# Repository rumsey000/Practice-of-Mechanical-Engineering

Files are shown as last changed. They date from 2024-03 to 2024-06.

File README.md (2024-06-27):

# 機械工程實務第二十六組專題
## 專題目標
本學年度機械⼯程實務將以分組⽅式完成⼀⾞輛的製作，此⾞輛利⽤環境⾵⼒作為驅動源，製作可將⾵⼒轉換為動⼒(如⾵帆)之機構，藉由控制該機構使⾞輛⾏進並轉向，完成⾃主⾏進任務，故名為AeroRide。
## 程式開發
### IMU
#### BY USING DMP
- 量測三軸加速度及三軸角速度，並使用MPU6050的DMP硬體來將前面提及的六項整合演算出yaw、roll和pitch的角度
- 主要使用 [ic2devlib](https://github.com/jrowberg/i2cdevlib) 這個開源程式庫內的檔案進行自動校正和資料讀取
#### BY USING KALMAN FILTER
- 量測三軸加速度及三軸角速度
- 重力加速度在三軸加速度的分量可算出yaw和roll的傾角，但剛開始測量時可能誤差較大。
- 角速度對時間的積分項亦能得出yaw和roll的傾角，但測量時間愈久誤差愈大。
- 使用卡爾曼濾波器來將前兩項融合出新的yaw和roll的傾角，其優勢在於可將其的缺點互相彌補，因而較為精準。
- 主要使用 [TKJ Electronics](https://github.com/TKJElectronics/KalmanFilter) 這個開源程式庫內的檔案進行資料讀取
- 校正部分則另外參考 [這個網站](https://wired.chillibasket.com/2015/01/calibrating-mpu6050/) 的程式並將讀取資料的函數改寫為上述開源程式庫的I2C通訊，將這個校正程式先跑一次後，再填入上述程式的偏移量中。
### MOTOR
#### DC motor
-期中使用的馬達，透過程式調整PID參數來達成角度控制
#### Servo motor
-期末使用的馬達，直接對MG996R輸PWM訊號來讓控制角度

## 參考網站
### ARDUINO
- [Arduino uno R3](https://docs.arduino.cc/resources/datasheets/A000066-datasheet.pdf)
- [SerialPlot（序列埠繪圖家）工具軟體（二）：安裝與執行SerialPlot - 超圖解系列圖書](https://swf.com.tw/?p=1591)
- [SerialPlot - Realtime Plotting Software | Hackaday.io](https://hackaday.io/project/5334-serialplot-realtime-plotting-software)
- [[C觀念] volatile 的用法和用意 @ 不會的就放這邊 :: 痞客邦 ::](https://anal02.pixnet.net/blog/post/117485340-%5Bc%5D-volatile-%E7%9A%84%E7%94%A8%E6%B3%95%E5%92%8C%E7%94%A8%E6%84%8F)
- [浅析C语言之uint8_t / uint16_t / uint32_t /uint64_t-CSDN博客](https://blog.csdn.net/mary19920410/article/details/71518130)
- [Arduino教程：使用millis()代替delay() – 趣讨教](https://www.qutaojiao.com/21429.html)
- [Arduino自定義庫的編寫 - 台部落](https://www.twblogs.net/a/5b833c9f2b71771e35c1ccf3)
### IMU
- [MPU-6000-Register-Map1.pdf](https://invensense.tdk.com/wp-content/uploads/2015/02/MPU-6000-Register-Map1.pdf)
- [I2C总线和通信协议详解](https://zhuanlan.zhihu.com/p/678229227)
- [Calibrating & Optimising the MPU6050 – chillibasket](https://wired.chillibasket.com/2015/01/calibrating-mpu6050/)
- [关于MPU6050的数据获取、分析与处理_matlab处理mpu6050原始数据-CSDN博客](https://blog.csdn.net/acktomas/article/details/89087174)
- [ASCII Table / character codes – SS64.com](https://ss64.com/ascii.html)
- [Pitch and Roll Estimation](https://www.nxp.com/docs/en/application-note/AN3461.pdf)
- [MPU6050 DMP freezes after random duration · Issue #519 · jrowberg/i2cdevlib · GitHub](https://github.com/jrowberg/i2cdevlib/issues/519)
- [position - 使用加速度计和陀螺仪计算位移 (MPU6050) - IT工具网](https://www.coder.work/article/6199777)
### DC MOTOR
- [NFP-JGA25-370-1260  12V DC datasheetModel ](https://nfpmotor.com/custom-gear-motor-6v12v24v-model-nfp-jga25-370)
- [3V, 6V, 12V DC Micro Metal Gearmotor JGA12-N20 | NFPmotor.com](https://nfpmotor.com/3v-6v-12v-dc-micro-metal-gearmotor-model-nfp-jga12-n20)
- [[RWG] 全新 高扭力 GM25-370 25GA370 直流減速馬達 帶編碼器 測速碼盤 | 蝦皮購物](https://shopee.tw/-RWG-%E5%85%A8%E6%96%B0-%E9%AB%98%E6%89%AD%E5%8A%9B-GM25-370-25GA370-%E7%9B%B4%E6%B5%81%E6%B8%9B%E9%80%9F%E9%A6%AC%E9%81%94-%E5%B8%B6%E7%B7%A8%E7%A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)
- [Stepper Motor with L298N and Arduino Tutorial (4 Examples)](https://www.makerguides.com/l298n-stepper-motor-arduino-tutorial/)
- [Arduino | 旋轉編碼器模組使用](https://hugheschung.blogspot.com/2018/06/arduino-1.html)
### SERVO MOTOR
- [MG90S_Tower-Pro.pdf](https://www.electronicoscaldas.com/datasheet/MG90S_Tower-Pro.pdf)
- [sg90_datasheet.pdf](http://www.ee.ic.ac.uk/pcheung/teaching/DE1_EE/stores/sg90_datasheet.pdf)
- [[Arduino範例] SG90 Servo伺服馬達](https://blog.jmaker.com.tw/arduino-servo-sg90/)
- [伺服馬達，回授控制入門 - 互動的風格 - Medium](https://medium.com/electronics-%E4%BA%92%E5%8B%95%E9%9B%BB%E5%AD%90/%E5%AF%A6%E9%AB%94%E9%81%8B%E7%AE%97week4-4943b619f476)
- [How to interface SG90 servo motor with Arduino](https://www.simplyiotsensors.com/2021/10/how-to-use-sg-90-servo-motor-with-Arduino.html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,of%20the%20motor%20it%20will%20consume%20100-250%20mA.)
### STEP MOTOR
- [[Arduino範例] ULN2003驅動板+28BYJ-48步進馬達](https://blog.jmaker.com.tw/uln2003-28byj-48/)
- [【產品/介紹】ULN2003 驅動板 + 28BYJ-48 步進馬達 - 台灣樹莓派](https://piepie.com.tw/8199/uln2003-stepper-motor-drive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,%E6%91%A9%E6%93%A6%E5%8A%9B%E7%9F%A9%EF%BC%9A600-1200%20gf.cm%20%E5%BC%95%E5%85%A5%E8%BD%89%E7%9F%A9%EF%BC%9A300%20gf.cm)
### SWITCH
- [《Arduino入門》第五篇：按鍵開關的使用](https://blog.jmaker.com.tw/arduino-buttons/)
- [Debounce on a Pushbutton | Arduino Documentation](https://docs.arduino.cc/built-in-examples/digital/Debounce/)
- [上拉電阻 - 維基百科，自由的百科全書](https://zh.wikipedia.org/zh-tw/%E4%B8%8A%E6%8B%89%E7%94%B5%E9%98%BB)
### MERCHANT
- [宇倉電子-全館(已含稅)開發票, 線上商店 | 蝦皮購物](https://shopee.tw/allen_6833?categoryId=100644&entryPoint=cart&itemId=64927673)
- [今華電子網路商城暨實體門市](https://jin-hua.com.tw/index.aspx)
- [廣華電子商城 - 敦華電子材料有限公司_網路郵購-電子材料-電子零件-臺灣 台中市](https://shop.cpu.com.tw/)
- [祥昌電子｜官方購物網 電子零售批發 電子耗材 IC半導體 儀錶 零組件 影音線材 手工具 電源供應器 3C 電子線](https://www.sconline.com.tw/tw/product/index.php?page=1&kind1=&kw=dc%E6%8E%A5%E9%A0%AD)
- [AWG WIRE TABLE](https://ken-gilbert.com/techstuff/AWG_WIRE_TABLE.html)
### SIMULATOR
- [New Arduino Uno Project - Wokwi Simulator](https://wokwi.com/projects/new/arduino-uno)
- [Circuit design Daring Esboo - Tinkercad](https://www.tinkercad.com/things/0wW5GkK5LwL-daring-esboo/editel?tenant=circuits)
- [BLOCK SVG EDIT V20231029](https://www.block.tw/bse/v20231029/)
- [Block Circuit EDIT](https://www.block.tw/bce/)
- [circuito.io](https://www.circuito.io/app?components=512,11021,11028,7654321)
### 3DCAD
- [麵包板](https://grabcad.com/library/mini-breadboard--1)
- [馬達驅動模組](https://grabcad.com/library/l298n-21)
- [18650電池盒](https://grabcad.com/library/4-x-18650-battery-box-1)
- [9V方型電池盒](https://grabcad.com/library/battery-box-9v-boitier-pour-pile-9-v-avec-interrupteur-on-off-1)
- [Arduino板](https://grabcad.com/library/arduino-uno-r3-11)
- [M4螺帽](https://www.mcmaster.com/products/nuts/hex-nuts~/thread-size~m4/)
- [M3螺帽](https://www.mcmaster.com/products/nuts/hex-nuts~/thread-size~m3/)
- [M3螺栓](https://www.mcmaster.com/products/screws/rounded-head-screws~/thread-size~m3/jis-steel-pan-head-screws/)
- [M4螺栓](https://www.mcmaster.com/products/screws/rounded-head-screws~/jis-steel-pan-head-screws/thread-size~m4/thread-size~m4/)
- [銅柱](https://www.mcmaster.com/products/male-female-threaded-hex-standoffs/male-female-threaded-hex-standoffs-6/thread-size~m3/)
### 成果展示
- <http://www.me.ntu.edu.tw/capstone/project.html>

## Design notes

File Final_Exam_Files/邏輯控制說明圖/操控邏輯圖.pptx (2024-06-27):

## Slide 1

升起、展開風帆

1.5s

按按鈕

0.5s

1.8s

旋轉風帆60度
平行風場

拿滿分
然後回宿舍睡覺

開始
煞車

停止
煞車

煞車

1.5s

3.8s

使用IML使
風帆平行第三風場

煞車

2.5s

使用IML使
風帆平行第一風場

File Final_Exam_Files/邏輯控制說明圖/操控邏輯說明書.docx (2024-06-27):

操控邏輯說明書

在圖1中的Start area將透過按鈕啟動arduino loop程式中的下一階段，而在圖1中的深橘色區塊，將透過程式計時0.5s後，車輪先煞車，再透過一顆mg996r伺服馬達旋轉160度升起主風帆，同時透過兩顆sg90伺服馬達旋轉90度展開側風帆，確認展開後，再鬆開煞車，這段期間預計車子將往前直線前進。

隨後，將透過另一顆mg996r伺服馬達做速度控制旋轉60度來讓其能順利得到風的推力，然後再煞車讓車子減速以避免下滑速度太快撞到草地，之後，透過IMU感測車底盤的旋轉量，將其配合mg996r伺服馬達的旋轉角度讓車身的旋轉不影響目前風帆的方向，讓風帆能持續得到推力，此一過程持續3.8秒讓其最後到達淺橘色區塊的60%分線附近。

隨後車子將煞車2.5秒，讓其不撞到圖1右上方的草地，之後風帆同樣受到IMU與伺服馬達的控制讓其與右上方的風機大致呈30度角，讓風帆得到推力將車子吹到終點。

上述過程大部分都以時間作為主要參數調整，可參考下方圖2。

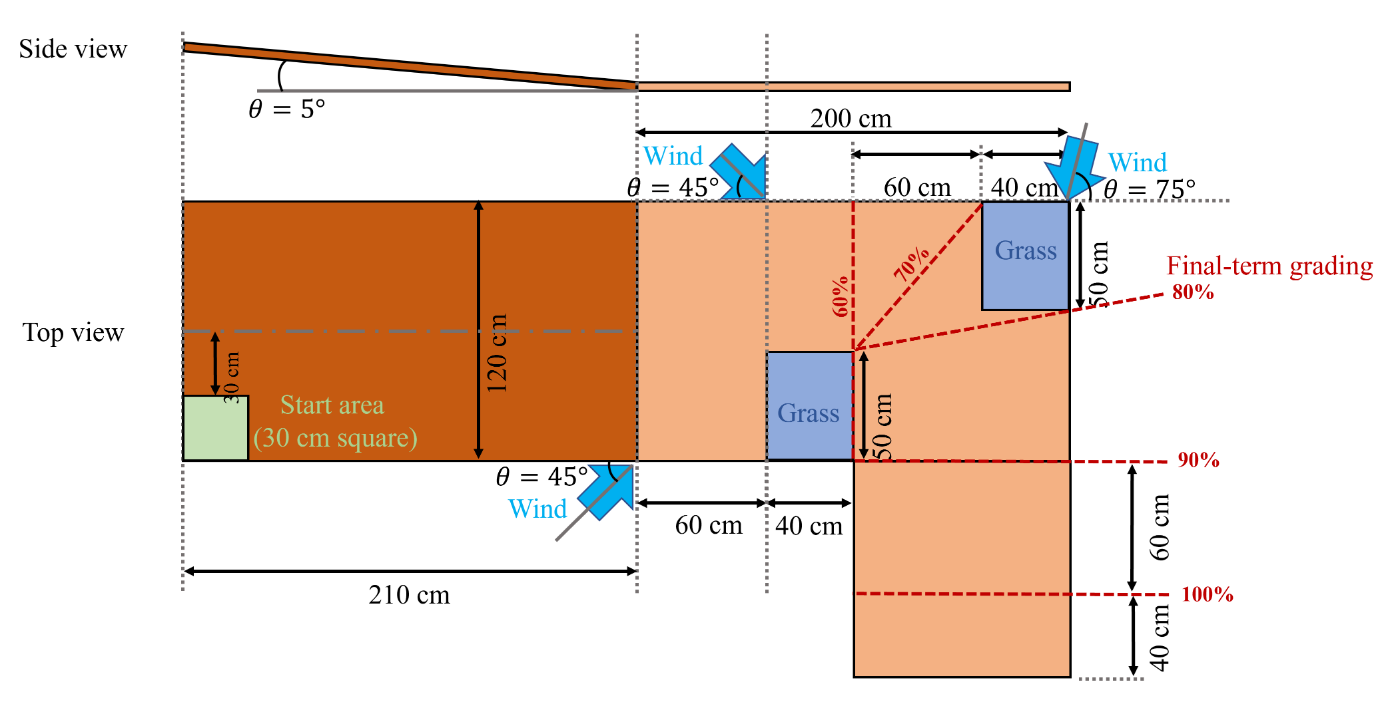
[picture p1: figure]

圖1、賽道示意圖

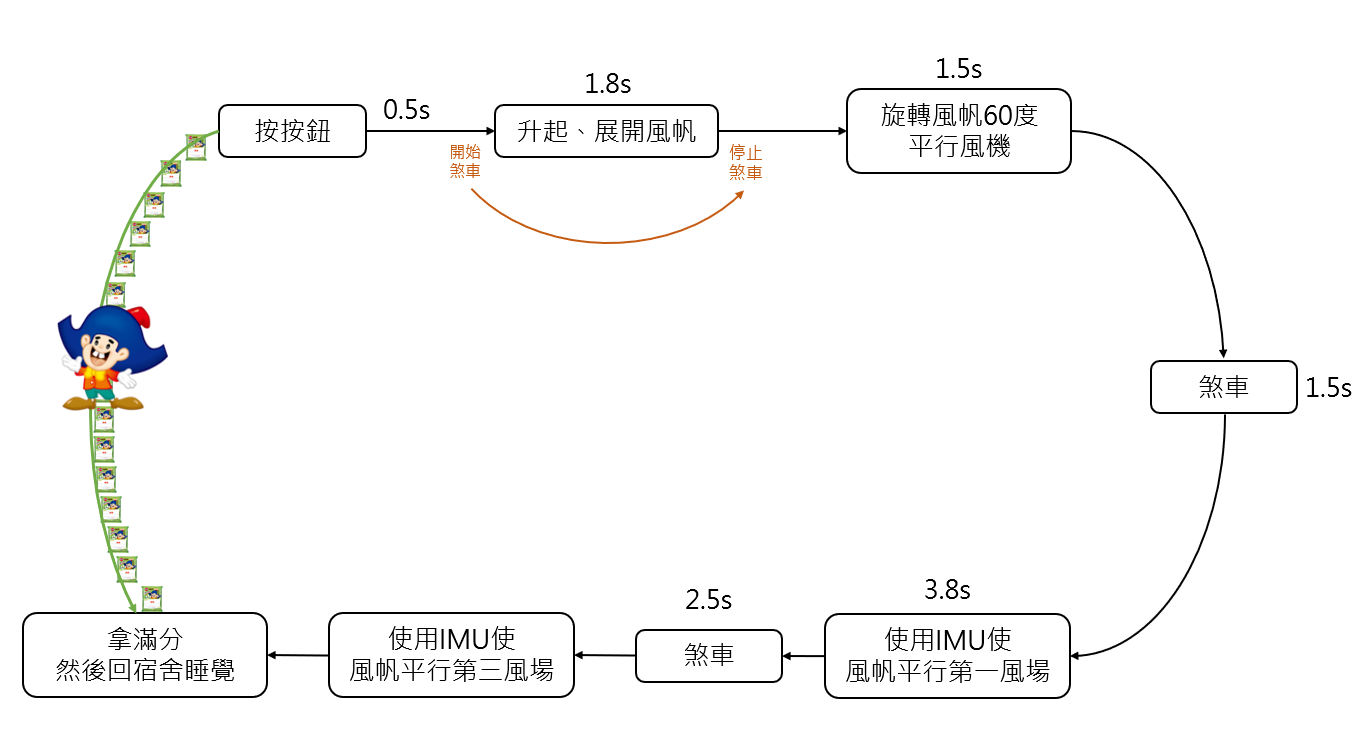
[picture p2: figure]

圖2、時間流程圖

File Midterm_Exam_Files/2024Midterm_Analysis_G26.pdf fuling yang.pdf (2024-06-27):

# Mid-term analysis report

# #OGTh

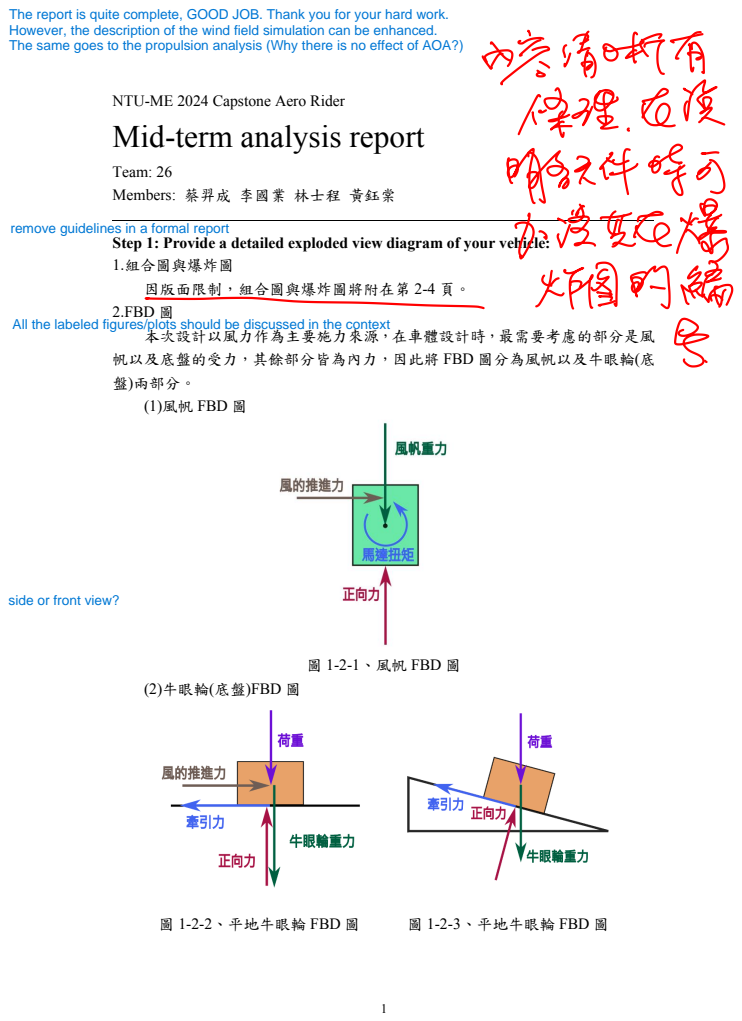
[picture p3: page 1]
圖 1-2-1、風帆 FBD 圖; 圖 1-2-2、平地牛眼輪 FBD 圖; 圖 1-2-3、平地牛眼輪 FBD 圖; Ri G Dre

NTU-ME 2024 Capstone Aero Rider

Team: 26
Members: 蔡羿成 李國業 林士程 黃鈺棠
因版面限制，組合圖與爆炸圖將附在第 2-4 頁。
2.FBD 圖
本次設計以風力作為主要施力來源，在車體設計時，最需要考慮的部分是風
帆以及底盤的受力，其餘部分皆為內力，因此將 FBD 圖分為風帆以及牛眼輪(底
盤)兩部分。
(1)風帆 FBD 圖

Step 1: Provide a detailed exploded view diagram of your vehicle:
1.組合圖與爆炸圖

(2)牛眼輪(底盤)FBD 圖

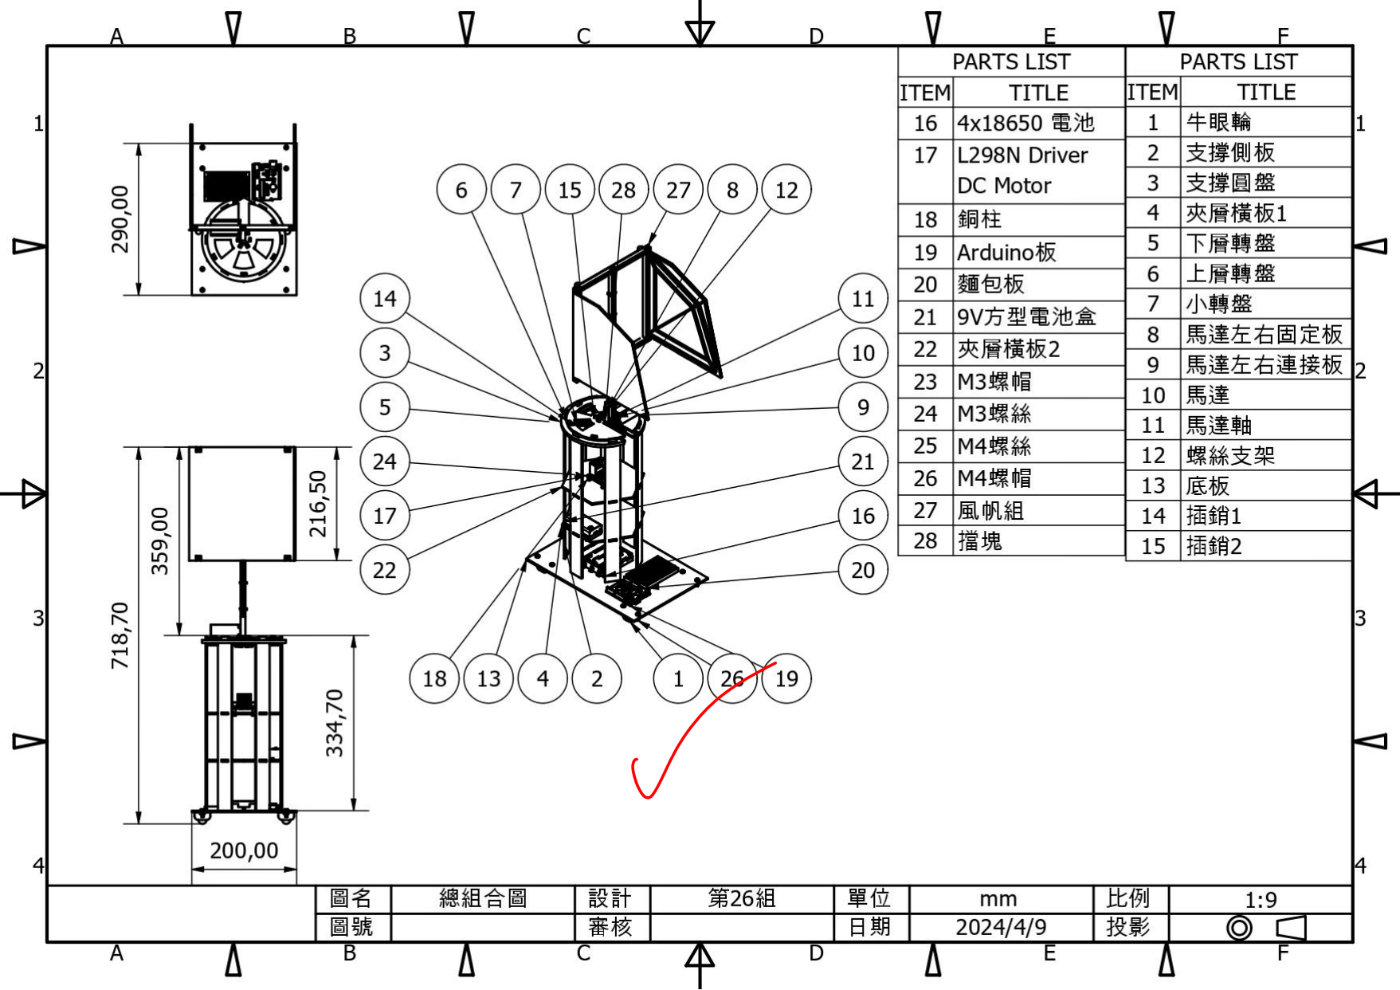
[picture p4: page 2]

2

~

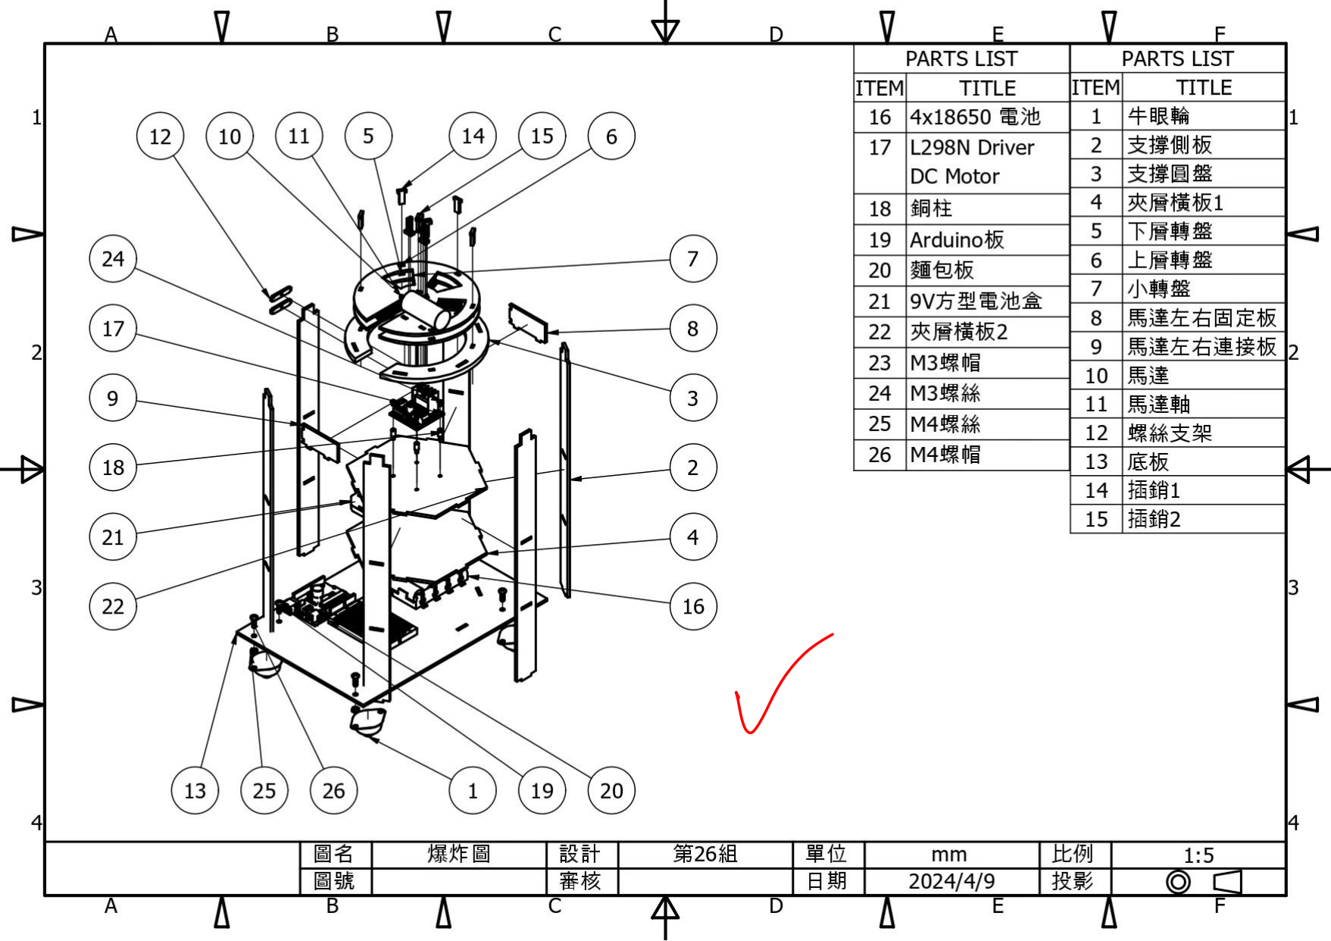
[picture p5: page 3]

3

~

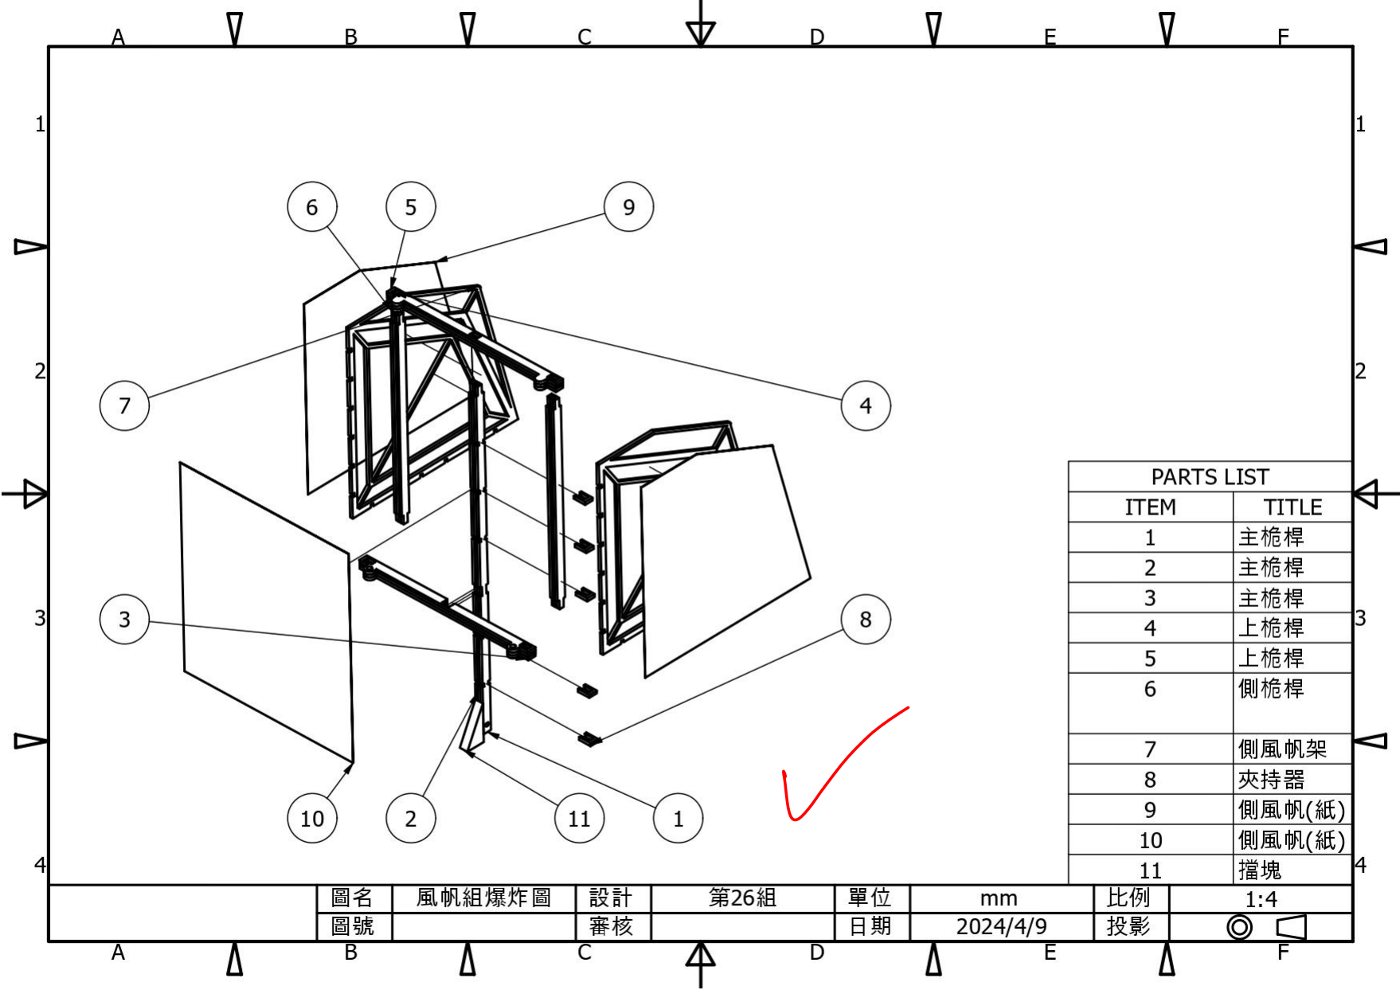
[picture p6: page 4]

4

~

# why not ?

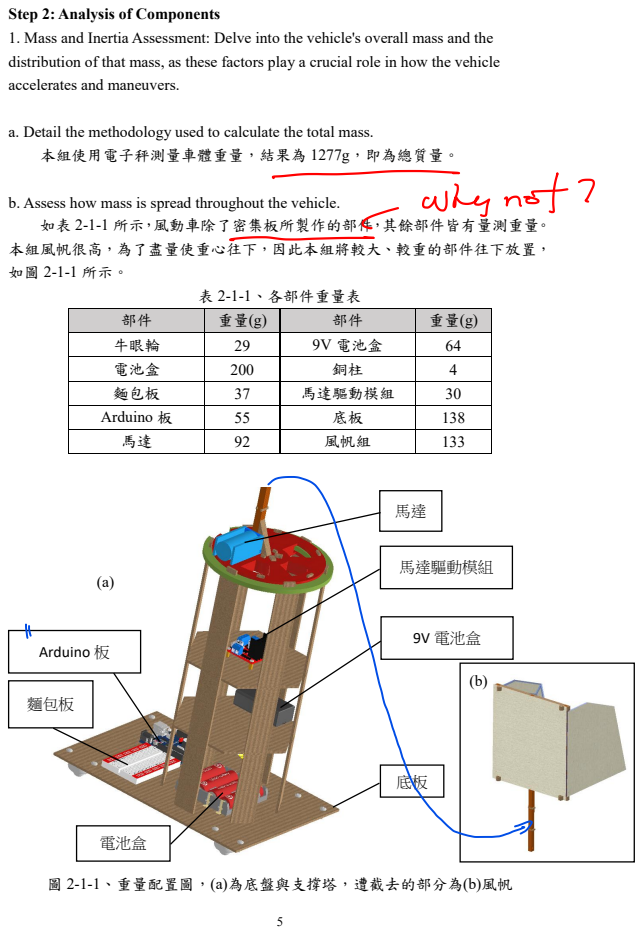
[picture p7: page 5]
表 2-1-1、各部件重量表; 馬達驅動模組; 9V 電池盒; Arduino 板; 麵包板; 電池盒

Step 2: Analysis of Components
1. Mass and Inertia Assessment: Delve into the vehicle's overall mass and the
distribution of that mass, as these factors play a crucial role in how the vehicle
accelerates and maneuvers.

a. Detail the methodology used to calculate the total mass.
本組使用電子秤測量車體重量，結果為 1277g，即為總質量。

b. Assess how mass is spread throughout the vehicle.
如表 2-1-1 所示，風動車除了密集板所製作的部件，其餘部件皆有量測重量。
本組風帆很高，為了盡量使重心往下，因此本組將較大、較重的部件往下放置，

部件 | 重量(g) | 部件 | 重量(g)
牛眼輪 | 29 | 9V 電池盒 | 64
電池盒 | 200 | 銅柱 | 4
麵包板 | 37 | 馬達驅動模組 | 30
Arduino 板 | 55 | 底板 | 138
馬達 | 92 | 風帆組 | 133

圖 2-1-1、重量配置圖，(a)為底盤與支撐塔，遭截去的部分為(b)風帆

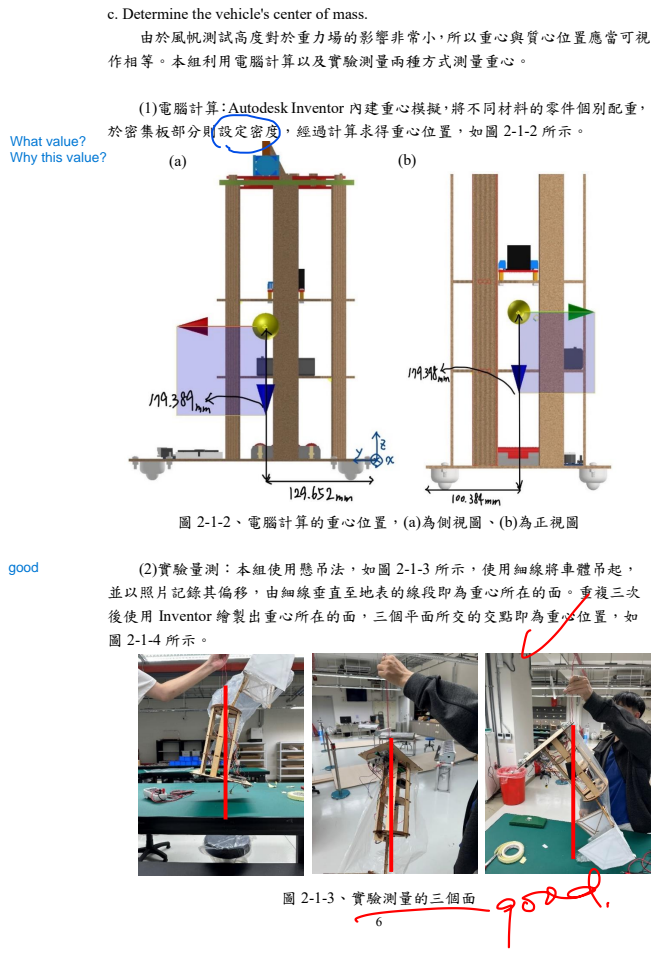
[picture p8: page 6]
圖 2-1-3、實驗測量的三個面; -good.

c. Determine the vehicle's center of mass.
由於風帆測試高度對於重力場的影響非常小，所以重心與質心位置應當可視
作相等。本組利用電腦計算以及實驗測量兩種方式測量重心。

(1)電腦計算：Autodesk Inventor 內建重心模擬，將不同材料的零件個別配重，
於密集板部分則設定密度，經過計算求得重心位置，如圖 2-1-2 所示。

圖 2-1-2、電腦計算的重心位置，(a)為側視圖、(b)為正視圖

(2)實驗量測：本組使用懸吊法，如圖 2-1-3 所示，使用細線將車體吊起，
並以照片記錄其偏移，由細線垂直至地表的線段即為重心所在的面。重複三次
後使用 Inventor 繪製出重心所在的面，三個平面所交的交點即為重心位置，如

圖 2-1-4、Inventor 產生三平面交點與位置

使用兩種方法的重心位置相差為：∆x = 18.51mm， ∆y = 2.79mm，∆z = 5.79mm，透過懸吊法量測重心的位置與 Inventor 模擬的結果在 x 方向差距 1.85cm， 與 inventor 結果相差不大，因此使用 inventor 模擬結果作為重心，在均勻重力場 下，質心位置即為重心位置。

2. Wheel Traction Evaluation: Analyze the grip (friction) between the tires and the surface, a critical factor for steering and braking efficiency. Consider how the vehicle's weight, the type of surface it's on, and the tire material affect traction.
a. Outline the approach for assessing wheel traction.

車子從斜坡上滑下來的過程可視為由重力和車輪牽引力的合力所做的加速 度運動。本組假設牽引力為滾動摩擦力、只與接觸材料和正向力有關，在斜坡上 滑行的過程中則可視為定值，下滑過程便可視為等加速度運動。因此我們選擇量 測車頭由起始點滑下到平面與斜面交界處所需的時間，藉由等加速度公式：

t = √²h

ax

(2 − 2 − 1)

其中 t 為所需時間，h 為車頭自起點滑至平面與斜面交界處的距離，ax是沿斜坡

(a) (b)

# good

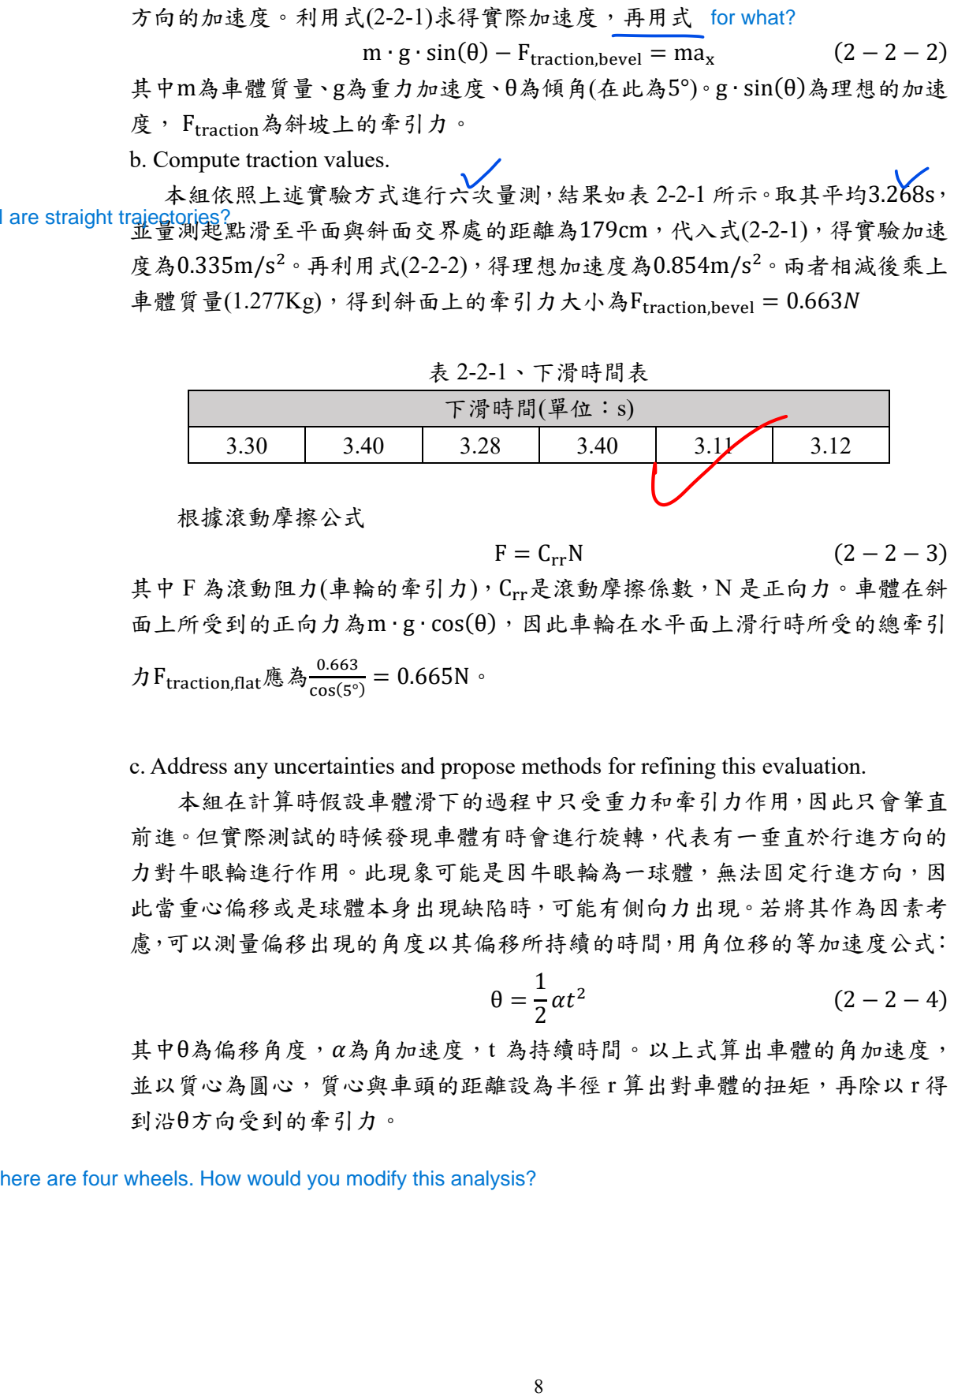
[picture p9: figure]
方向的加速度。利用式(2-2-1)求得實際加速度，再用式; 其中m為車體質量、g為重力加速度、θ為傾角(在此為5°)。g ∙ sin(θ)為理想的加速; 度， Ftraction為斜坡上的牽引力。 b. Compute traction values. 本組依照上述實驗方式進行六次量測，結果如表 2-2-1 所示。取其平均3.268s，; 並量測起點滑至平面與斜面交界處的距離為179cm，代入式(2-2-1)，得實驗加速 度為0.335m/s²; 。再利用式(2-2-2)，得理想加速度為0.854m/s² 。兩者相減後乘上 車體質量(1.277Kg)，得到斜面上的牽引力大小為Ftraction,bevel = 0.663N; 表 2-2-1、下滑時間表; 下滑時間(單位：s); 根據滾動摩擦公式; F = CrrN; 其中 F 為滾動阻力(車輪的牽引力)，Crr是滾動摩擦係數，N 是正向力。車體在斜; 面上所受到的正向力為m ∙ g ∙ cos(θ)，因此車輪在水平面上滑行時所受的總牽引; 力Ftraction,flat應為 0.663 cos(5°) = 0.665N。; 本組在計算時假設車體滑下的過程中只受重力和牽引力作用，因此只會筆直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

m ∙ g ∙ sin(θ) − Ftraction,bevel = max | (2 − 2 − 2)
c. Address any uncertainties and propose methods for refining this evaluation.

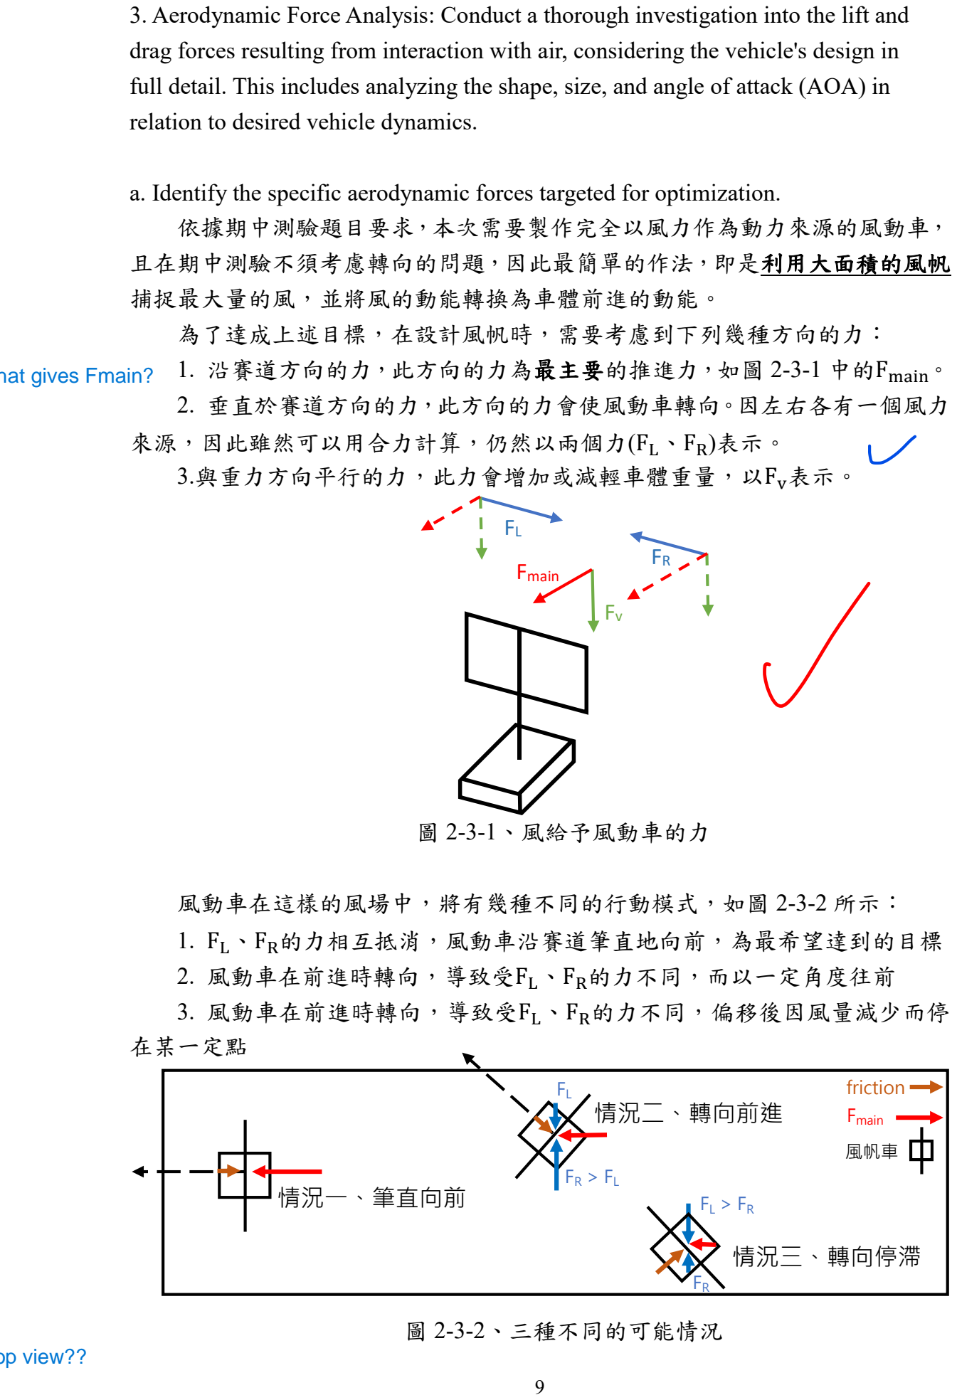
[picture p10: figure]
relation to desired vehicle dynamics.; 依據期中測驗題目要求，本次需要製作完全以風力作為動力來源的風動車，; 且在期中測驗不須考慮轉向的問題，因此最簡單的作法，即是利用大面積的風帆; 捕捉最大量的風，並將風的動能轉換為車體前進的動能。; 為了達成上述目標，在設計風帆時，需要考慮到下列幾種方向的力：; 2. 垂直於賽道方向的力，此方向的力會使風動車轉向。因左右各有一個風力; 來源，因此雖然可以用合力計算，仍然以兩個力(FL、FR)表示。 3.與重力方向平行的力，此力會增加或減輕車體重量，以Fv表示。; 圖 2-3-1、風給予風動車的力; 風動車在這樣的風場中，將有幾種不同的行動模式，如圖 2-3-2 所示：; 1. FL、FR的力相互抵消，風動車沿賽道筆直地向前，為最希望達到的目標; 2. 風動車在前進時轉向，導致受FL、FR的力不同，而以一定角度往前 3. 風動車在前進時轉向，導致受FL、FR的力不同，偏移後因風量減少而停; 在某一定點; 圖 2-3-2、三種不同的可能情況; FR Fmain; 情況一、筆直向前; 情況二、轉向前進; 情況三、轉向停滯; Fmain; friction; 風帆車

3. Aerodynamic Force Analysis: Conduct a thorough investigation into the lift and drag forces resulting from interaction with air, considering the vehicle's design in full detail. This includes analyzing the shape, size, and angle of attack (AOA) in
a. Identify the specific aerodynamic forces targeted for optimization.
1. 沿賽道方向的力，此方向的力為最主要的推進力，如圖 2-3-1 中的Fmain。

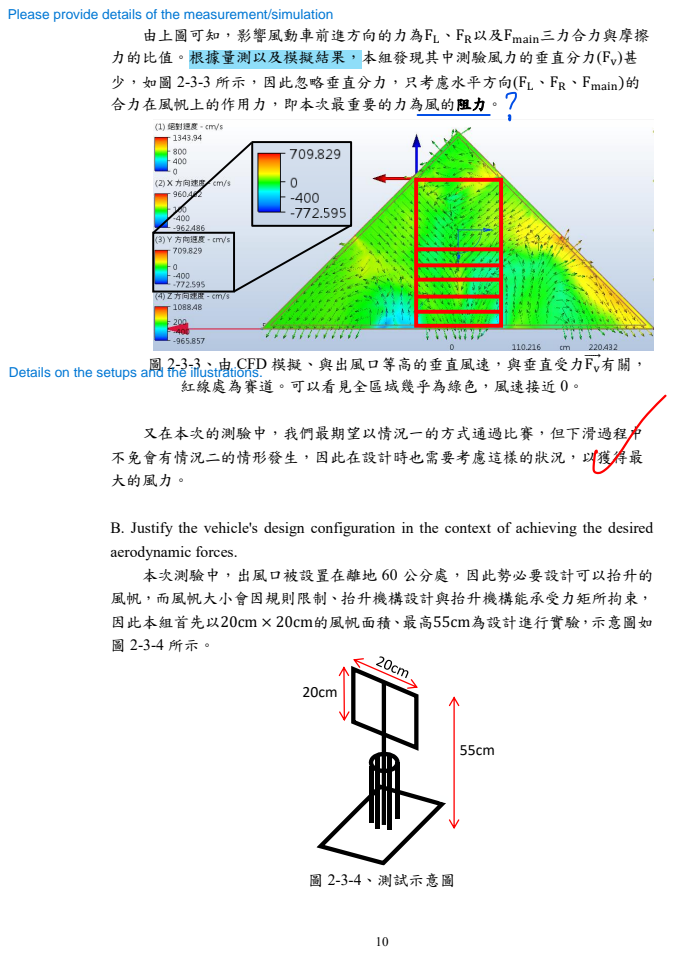
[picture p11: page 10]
圖 2-3-4、測試示意圖

由上圖可知，影響風動車前進方向的力為FL、FR以及Fmain三力合力與摩擦
力的比值。根據量測以及模擬結果，本組發現其中測驗風力的垂直分力(Fv)甚
少，如圖 2-3-3 所示，因此忽略垂直分力，只考慮水平方向(FL、FR、Fmain)的
合力在風帆上的作用力，即本次最重要的力為風的阻力。

圖 2-3-3、由 CFD 模擬、與出風口等高的垂直風速，與垂直受力Fv ⃗ 有關，
紅線處為賽道。可以看見全區域幾乎為綠色，風速接近 0。

又在本次的測驗中，我們最期望以情況一的方式通過比賽，但下滑過程中
不免會有情況二的情形發生，因此在設計時也需要考慮這樣的狀況，以獲得最
大的風力。

B. Justify the vehicle's design configuration in the context of achieving the desired
aerodynamic forces.
本次測驗中，出風口被設置在離地 60 公分處，因此勢必要設計可以抬升的
風帆，而風帆大小會因規則限制、抬升機構設計與抬升機構能承受力矩所拘束，
因此本組首先以20cm × 20cm的風帆面積、最高55cm為設計進行實驗，示意圖如

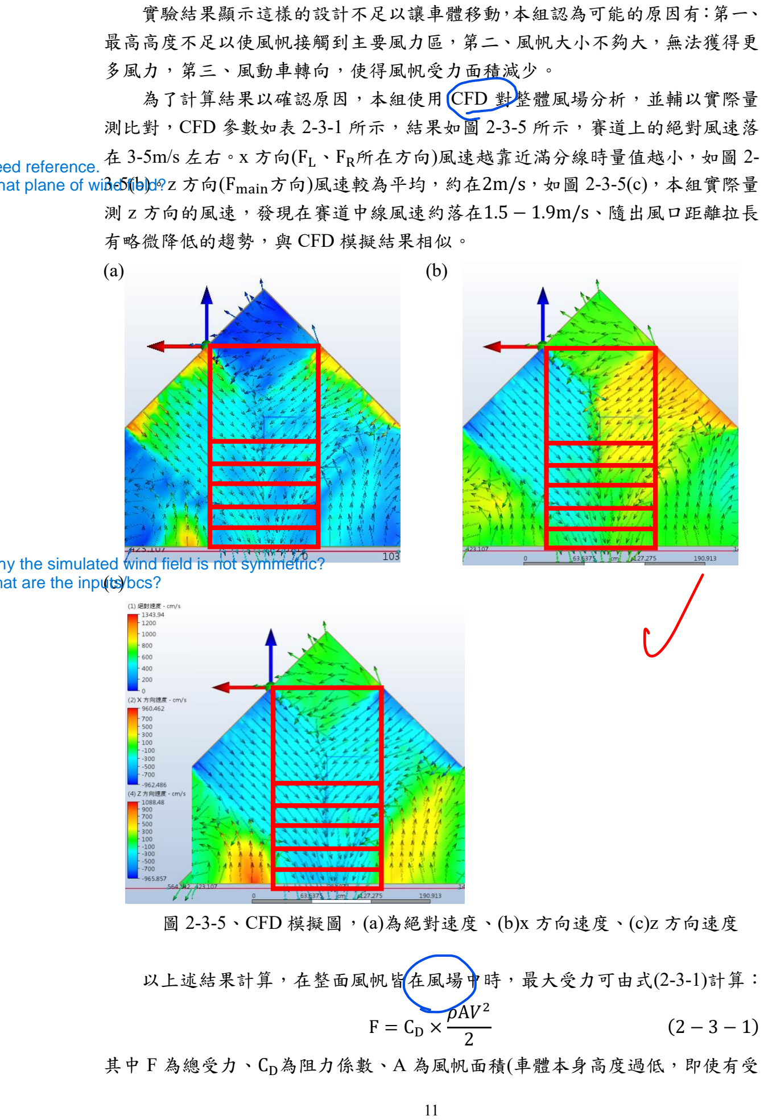
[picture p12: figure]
實驗結果顯示這樣的設計不足以讓車體移動，本組認為可能的原因有：第一、; 最高高度不足以使風帆接觸到主要風力區，第二、風帆大小不夠大，無法獲得更; 多風力，第三、風動車轉向，使得風帆受力面積減少。 為了計算結果以確認原因，本組使用 CFD 對整體風場分析，並輔以實際量; 在 3-5m/s 左右。x 方向(FL、FR所在方向)風速越靠近滿分線時量值越小，如圖 2- 3-5(b)。z 方向(Fmain方向)風速較為平均，約在2m/s，如圖 2-3-5(c)，本組實際量; 測 z 方向的風速，發現在賽道中線風速約落在1.5 − 1.9m/s、隨出風口距離拉長; 有略微降低的趨勢，與 CFD 模擬結果相似。 (a) (b); 圖 2-3-5、CFD 模擬圖，(a)為絕對速度、(b)x 方向速度、(c)z 方向速度; 以上述結果計算，在整面風帆皆在風場中時，最大受力可由式(2-3-1)計算：; F = CD × ρAV²; 其中 F 為總受力、CD為阻力係數、A 為風帆面積(車體本身高度過低，即使有受

測比對，CFD 參數如表 2-3-1 所示，結果如圖 2-3-5 所示，賽道上的絕對風速落

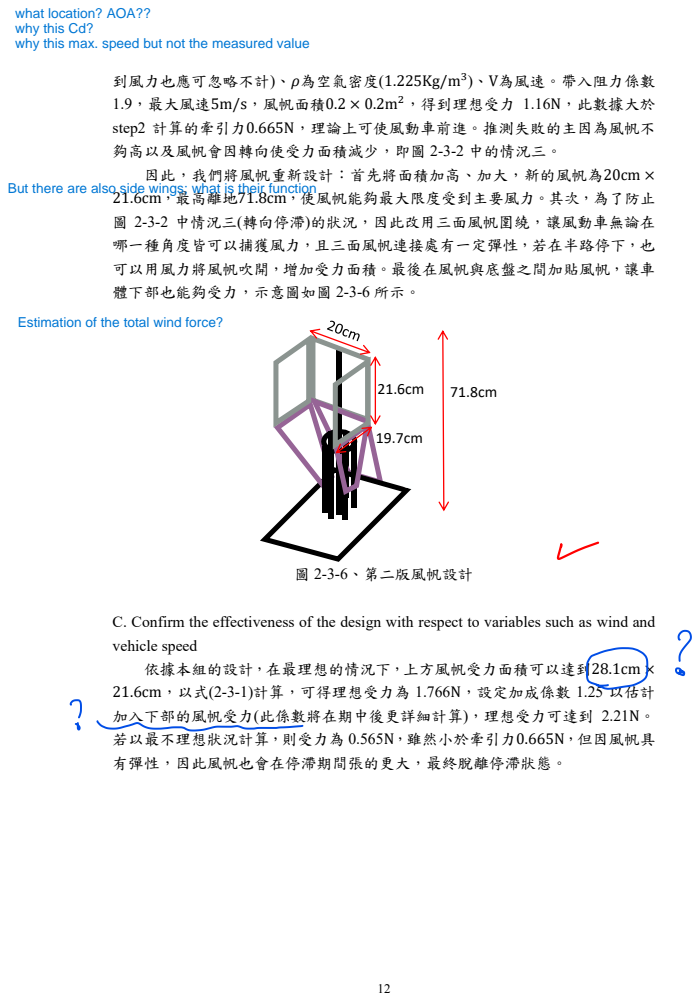
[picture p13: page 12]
圖 2-3-6、第二版風帆設計

到風力也應可忽略不計)、ρ為空氣密度(1.225Kg/m³)、V為風速。帶入阻力係數
1.9，最大風速5m/s，風帆面積0.2 × 0.2m²，得到理想受力 1.16N，此數據大於
step2 計算的牽引力0.665N，理論上可使風動車前進。推測失敗的主因為風帆不
夠高以及風帆會因轉向使受力面積減少，即圖 2-3-2 中的情況三。
因此，我們將風帆重新設計：首先將面積加高、加大，新的風帆為20cm ×
21.6cm，最高離地71.8cm，使風帆能夠最大限度受到主要風力。其次，為了防止
圖 2-3-2 中情況三(轉向停滯)的狀況，因此改用三面風帆圍繞，讓風動車無論在
哪一種角度皆可以捕獲風力，且三面風帆連接處有一定彈性，若在半路停下，也
可以用風力將風帆吹開，增加受力面積。最後在風帆與底盤之間加貼風帆，讓車
體下部也能夠受力，示意圖如圖 2-3-6 所示。

C. Confirm the effectiveness of the design with respect to variables such as wind and
vehicle speed
依據本組的設計，在最理想的情況下，上方風帆受力面積可以達到28.1cm ×
21.6cm，以式(2-3-1)計算，可得理想受力為 1.766N，設定加成係數 1.25 以估計
加入下部的風帆受力(此係數將在期中後更詳細計算)，理想受力可達到 2.21N。
若以最不理想狀況計算，則受力為 0.565N，雖然小於牽引力0.665N，但因風帆具
有彈性，因此風帆也會在停滯期間張的更大，最終脫離停滯狀態。

4. Steering and Unfolding Mechanism Overview: Present a detailed explanation of how your steering or unfolding mechanism can harness wind energy to aid in vehicle navigation.
a. Showcase the mechanism's design and operational principles.
展開機構如圖 2-4-1 所示，由馬達、桅杆及風帆組成，馬達的功能為提供桅杆 轉動所需的動力，風帆的功能則為增加受力面積。

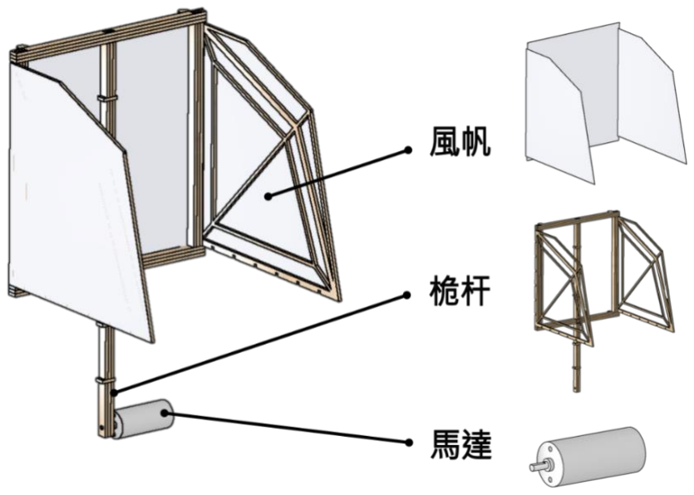
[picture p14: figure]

圖 2-4-1、展開機構
該機構的運作原理是馬達會將桅杆帶動到最高點，再透過風帆盡可能地汲 取風的推力，因為馬達的角度控制是機構能否成功的關鍵，所以本組將該馬達 搭配微控制器、編碼器與馬達驅動模組組成 PID 負回饋控制系統，如圖 2-4-2 所示，來精確地控制馬達軸旋轉到目標角度。
運作時，與馬達軸連接的編碼器將不斷向微控制器發送資料，微控制器再 以該資料推得馬達軸的當下角度，並藉由比較其與目標角度的差和kp、ki與kd 的值來輸出 PWM 與轉向訊號給馬達驅動模組，透過其來供給馬達足夠的電壓 和調整當下的轉速和轉向，最終，讓馬達軸旋轉到目標角度。

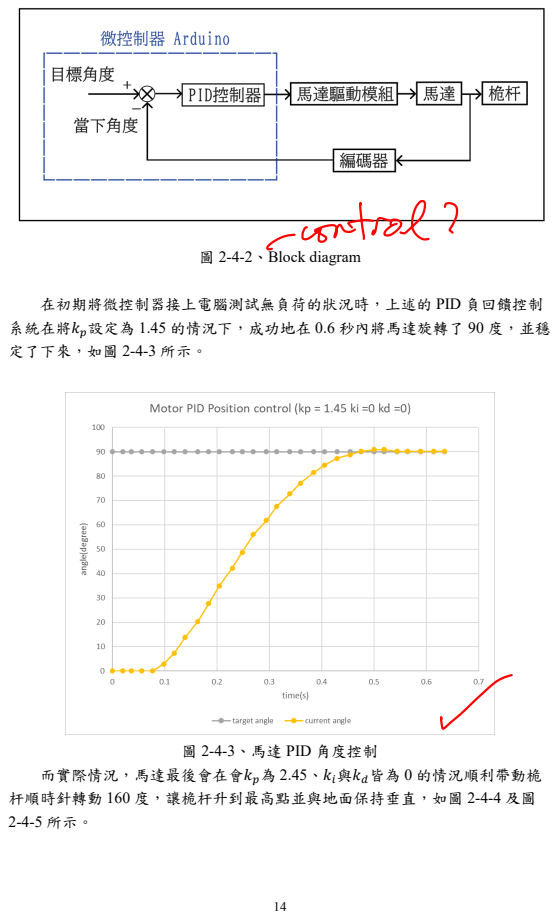
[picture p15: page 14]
圖 2-4-2、Block diagram; -untrol ?

在初期將微控制器接上電腦測試無負荷的狀況時，上述的 PID 負回饋控制
系統在將kp設定為 1.45 的情況下，成功地在 0.6 秒內將馬達旋轉了 90 度，並穩
定了下來，如圖 2-4-3 所示。

圖 2-4-3、馬達 PID 角度控制

而實際情況，馬達最後會在會kp為 2.45、ki與kd皆為 0 的情況順利帶動桅
杆順時針轉動 160 度，讓桅杆升到最高點並與地面保持垂直，如圖 2-4-4 及圖

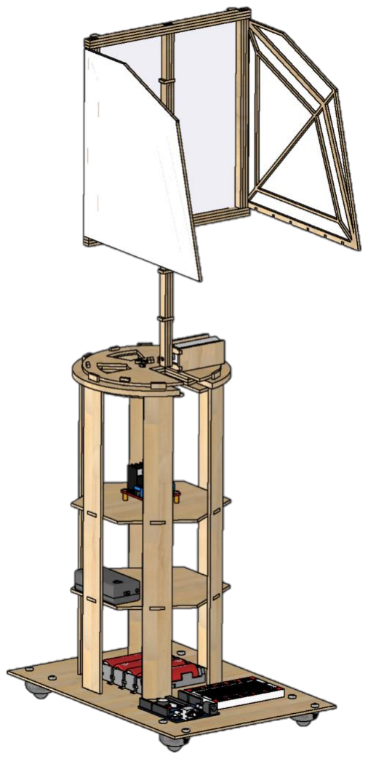
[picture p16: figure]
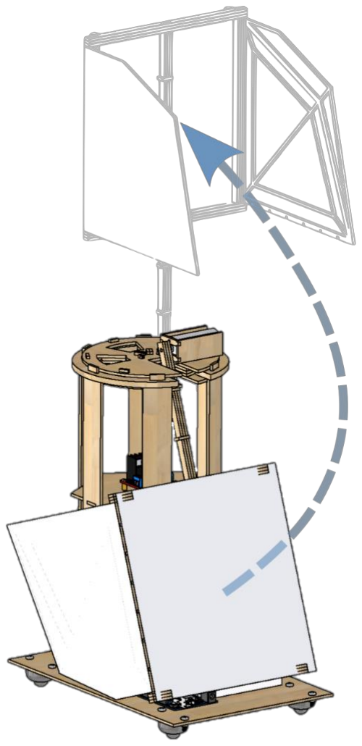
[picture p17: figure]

圖 2-4-4、展開過程示意圖 | 圖 2-4-5、完整展開圖
b. Clarify how the mechanism contributes to vehicle control.
該展開機構會將風帆升到約 50 到 70 公分的高度，因而可阻攔約在 60 公分 處的風，周圍的空氣分子也因此在風帆的受風面產生高壓區，風帆的背風面產生 低壓區，兩區的壓力差與風帆面積積分後算出的推力，將推動風帆帶動車子往風 帆的背風面前進，因而能控制車子的前後方向。
c. Evaluate the mechanism's current performance and suggest potential enhancements or modifications for the future.
該機構的表現能分為風帆效能和馬達控制兩個部分評估。
風帆部分，在馬達有將桅杆上升到最高點的情況下，每次測試階段都能跑 到終點，但所花時間仍然不太穩定，主因是若車子因牛眼輪或風所造成的推力 發生偏轉，就只能靠風帆左右兩側的其中一側得到推力，但由於其面積相對中 間的帆來得小，而造成須花較多時間來前進，因而風帆效能的部分仍有待加 強。
要改善上述的風帆效能，未來可考慮用伺服馬達張開左右兩側的風帆來增 加受力表面積，並使用陀螺儀偵測車子偏轉角度，再根據偏轉程度來調整伺服 馬達的角度，使車體能再被風的推力轉正，以改善偏轉問題，並讓風帆效能有 進一步的提升。
馬達部分，雖然每次放下車子的位置不同都會造成操作環境的稍許變動，

但在調整完 PID 參數後，幾乎測試時都能以肉眼觀察到桅杆有上升到最高點， 因而馬達控制的部分在現階段仍不用太擔心。
但考慮到未來要增加帆及伺服馬達的情況下，kp勢必只能調大，若有觀察 到轉動時有過衝、穩態誤差過大或震盪情況發生時，將根據表 2-4-1 調整ki與kd 來使馬達轉動情形得到改善。此外，由於無另外添購無線通訊的電子元件，目 前仍只能在接電腦的情況下，測得馬達的當前角度與目標角度，因而可在期末 測驗前考慮加裝通訊設備或其他方法來測得馬達在賽道上的實際轉角。

表 2-4-1 PID 參數調整方法表
調整方式 | Rise time | Overshoot | Settling time | Steady state error | Stability
kp增加 | 減少 | 增加 | 小幅增加 | 減少 | 變差
ki增加 | 小幅減少 | 增加 | 增加 | 大幅減少 | 變差
kd增加 | 小幅減少 | 減少 | 減少 | 變動不大 | 便好
Step 3: Vehicle Dynamics Integration
Synthesize the previously discussed elements to formulate a dynamic equation for the Aero Rider.
1. Craft an Equation of Motion (in vector or abstract form):
a. Clearly define each variable, ensuring dimensional consistency across all terms.
b. Provide a detailed explanation for each component of the equation. 運動方程式可以分為斜坡上的方程式以及平地上的方程式： (1)斜坡上的方程式：
m ∙ ⃗g ∙ sin(θ) − F⃗
traction,bevel = ma⃗ x,bevel | (3 − 1 − 1)
F⃗
traction,bevel = CrrN = Crr ∙ m ∙ g ∙ cos(θ) | (3 − 1 − 2)
其中
(a) m為車體質量，單位為Kg
(b) ⃗g 為重力加速度，單位為m/s²
(c) θ為傾角，(2)-(3)組合即為理想的加速度g ∙ sin(θ)
(d) F⃗
traction,bevel為斜坡上的牽引力，單位為 N
(e) a⃗ x,bevel為沿斜坡方向加速度，單位為m/s²
(f) Crr為滾動摩擦係數
值得注意的是式(3-1-1)即為式(2-2-2)，式(3-1-2)即為式(2-2-3)。
(2) 平面上的方程式：
F⃗

wind + F⃗
traction,flat = ma⃗ x,flat | (3 − 1 − 3)
F⃗
traction,flat = mg | (3 − 1 − 4)

其中
(a) F⃗
wind為風給與風動車的力，單位為 N
(b) F⃗
traction,flat為平面上的牽引力，單位為 N
(c) a⃗ x,flat為往終點方向加速度，單位為m/s²
c. Outline the underlying assumptions made in the formulation. 在這些方程式中，我們假設:
(1)車體本身只受重力、牽引力和風力影響
(2)風帆所承受到的風力一直為最大值且不會變化
(3)車體筆直前行，不會旋轉
(4)風帆在受風區時維持垂直於水平面
2. Assess the Validity of Your Equations (through experimental measurements, numerical analyses, etc.):
a. Outline the methodology for using the equation to predict the Aero Rider's dynamics. 上述四條公式皆是以牛頓第二定律為基礎。在式(3-1-1)中，m ∙ g ∙ sin(θ)為沿 斜坡方向下的加速度，減去斜坡上的牽引力Ftraction,bevel，即為實際作用力max。 在(3-1-2)中，詳細說明了Ftraction,bevel即是以滾動摩擦的方式計算，只需要注意正 向力為m ∙ g ∙ cos(θ)。在(3-1-3)中，Fwind為風給與風動車的力，減去平面上的牽 引力Ftraction,flat，即是作用力max。(3-1-4)與(3-1-2)雷同，只需要注意正向力為mg。 以上述四式計算可得風動車在斜面以及在平面上的加速度，並可做進一步處 理獲得速度、時間等資訊。
b. Describe the process for deriving predictions from the equation.
將 step2 中所計算或量測的數據代入式(3-1-1)、式(3-1-2)，即可得知加速度： 1.277 ∙ 9.81 ∙ sin(5°) − F⃗
traction,bevel = 1.277a⃗ x | (3 − 2 − 1)
F⃗
traction,bevel = 0.663 | (3 − 2 − 2)
加速度a⃗ x,bevel為0.335m/s²，再帶入式(2-2-1)：

t = √²h

ax

= √² ∙ 1.79
0.335 | (2 − 2 − 1)

得到滑行時間tbevel = 3.278s，再使用公式：
v = axt ∙ cos(θ) = 0.335 ∙ 3.278 ∙ cos(5) | (3 − 2 − 3)
得終端速度為vbevel = 1.094m/s。將風給予的力設為最理想與最不理想的平均 (F⃗
wind = 1.387N )利用相同方式計算，得到從速度為零自平板上起跑到終點的加 速度a⃗ x,flat為0.565m/s²，滑行時間tflat = 2.661s，終端速度為vflat = 1.503m/s。

c. Benchmark these predictions against real-world behaviors or outcomes.
實驗結果如表 3-2-1 所示，在實驗時，本組發現滑行至平面時，風動車仍會 停頓，持續約 4 秒。由於未記錄在滑坡上的時長，因此只比較從暫停處到終點用 時。 相比於計算數據 2.661 秒，實驗數據大約為兩倍長，推測為風帆的效能估計 太過樂觀所致。
表 3-2-1、各項實驗資料
實驗 | 總時長(s) | 暫停時長(s) 暫停時與終點的距離(m) 暫停處到終點用時(s)
1 | 9.24 | 3.99 | 1.32 | 5.25
2 | 9.14 | 3.82 | 1.35 | 5.32
3 | 9.06 | 4.03 | 1.2 | 5.03
4 | 9.27 | 4.23 | 1.23 | 5.04
5 | 9 | 4.1 | 1.17 | 4.9
6 | 8.77 | 4.03 | 1.06 | 4.74
平均 | 9.08 | 4.0 | 1.22 | 5.05
3. Suggest Improvements for the Modeling/Testing Approach:
a. Reflect on any discrepancies observed between the predictions and actual outcomes. 在實際試驗中，我們發現進入流場的車子並不會隨著風力的推動筆直往前走， 而是會停在原地不動一段時間，然後才被風力推動，而前進所耗費的時間也比計 算來的慢很多。此外，在由斜坡道平面的過程中，也時常出現轉向的情況發生， 這也是在建立運動方程式時未討論到的部分。
b. Speculate on potential sources of error or misalignment in the model or testing process.
我們認為這樣的現象可能來自於對風帆受力的預期過於樂觀，由於風帆會隨 著車體轉向而改變角度，在以不同角度面對風機時車體會有不同的速度，原本的 理想風推力 2.21N 是由理想受力 1.766N 乘上係數 1.25 所得，根據實際情況計算， 加速度的平均值為0.096m/s²，得出的實際推力應為 0.785N，代表我們的風帆並 未能擷取到大部分的風力。此外，我們沒有將平面分成未進入風場以及進入風場 兩部分討論，使得在剛進入平面而尚未進入風場的區段也被計算成有進入風場的 情況，使得用時被低估。
c. Propose strategies to address and rectify these discrepancies for more accurate future modeling.
鑒於上述討論，本組認為需要對以下幾點改善、建立更準確的評估模式：
(1) 除了中線上的風場量測外，本組往後將量測更多個數據點，以求精準
(2) 運動方程式應當加入轉角對車體運動、風帆受力的影響
(3) 平面區段應更細分為未進入風場以即進入風場兩區
(4) 風帆的加成係數需要準確量測或利用(1)中獲得更精確的數據計算

Step 4: Summary and Conclusions
本組利用塔加上抬升風帆的方式將風帆抬至風速最大的區間之中，利用風力 驅動車體移動。風帆以 U 字形設計，確保無論車體如何轉向，風帆皆能夠接收風 力。在沒有 U 字形設計時，車體無法前進；加入 U 字形設計後。在六次的實驗 中，平均耗時 9.08 秒完成一趟測試；在一次的模擬正式測驗中，花費 2 分 06 秒 完成測試且每次均達 100 分線，證實這項設計的成效以及其必要性。 本組的設計優點在於做動機構簡單、方便維修，且設計轉盤，為以後的轉向 保留擴充空間，零件雖較多但體積小，重製、替換成本較低等。缺點在於：在最 極端的情況下仍有可能使車體無法前進，許多需要旋轉的部件會因磨損而需要替 換等。解決方案為將易磨損零件的材質由合板改為 3D 列印之塑膠，增加強度， 風帆設計更好的展開模式，加大受力面積。
對於期末的測試，本組在風帆與機構部分事先保留轉向設計－實際上此時便 可以轉向，但本組有使用插銷固定轉盤－因此在轉向上只需加入機電元件便可， 如圖 4-1 所示。風帆也預留展開設計，可以進一步將最大受力面積擴張為現在的 三倍，如圖 4-2 所示。位置資訊則預計由陀螺儀獲得。

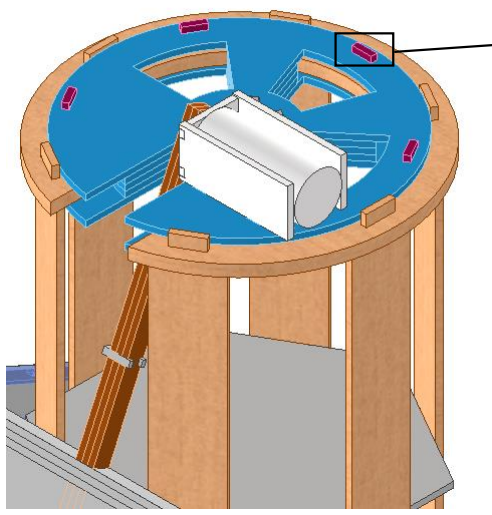
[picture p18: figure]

圖 4-1、轉盤設計，藍色為轉盤，深紅色為插銷

插銷

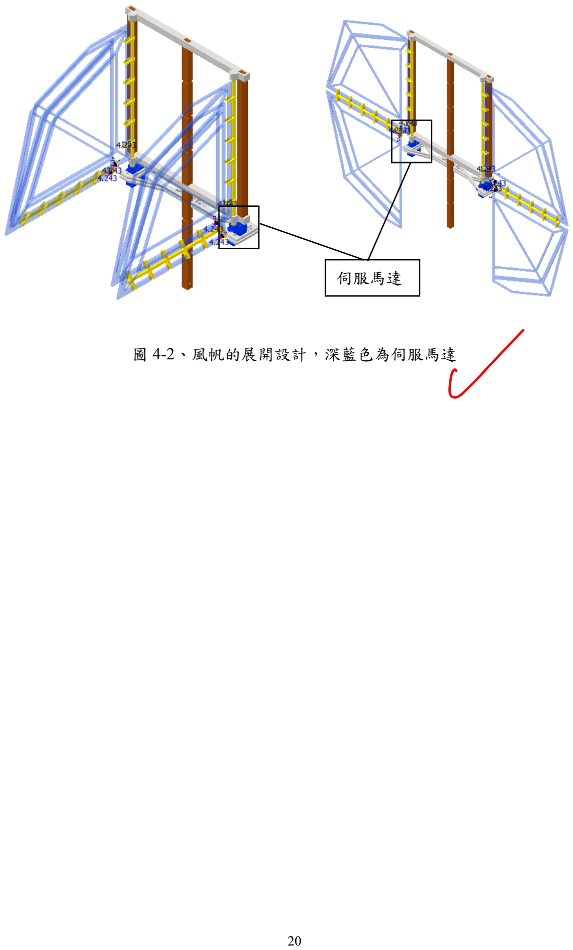
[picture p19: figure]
圖 4-2、風帆的展開設計，深藍色為伺服馬達; 伺服馬達

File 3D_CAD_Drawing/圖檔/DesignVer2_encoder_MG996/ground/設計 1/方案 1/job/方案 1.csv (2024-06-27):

CPU time | 58.133
memory | 163962880
fluid nodes | 67949
solid nodes | 0
fluid elements | 259369
solid elements | 0

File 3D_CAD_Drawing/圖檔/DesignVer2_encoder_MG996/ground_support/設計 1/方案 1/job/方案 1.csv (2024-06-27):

CPU time | 55.381
memory | 164405248
fluid nodes | 67949
solid nodes | 0
fluid elements | 259369
solid elements | 0

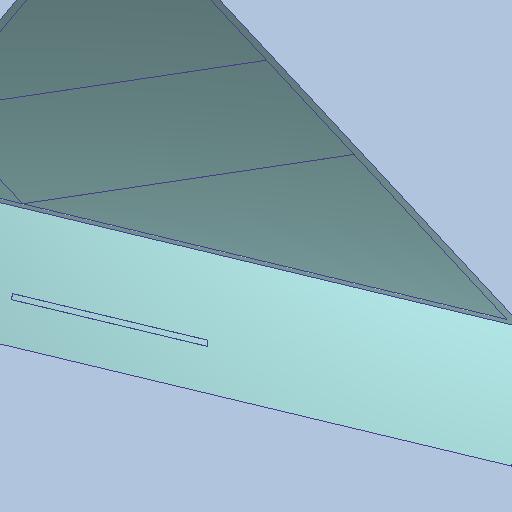
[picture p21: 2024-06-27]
3D_CAD_Drawing/圖檔/DesignVer2_encoder_MG996/ground_support/設計 1/方案 1/thumbnail.jpg

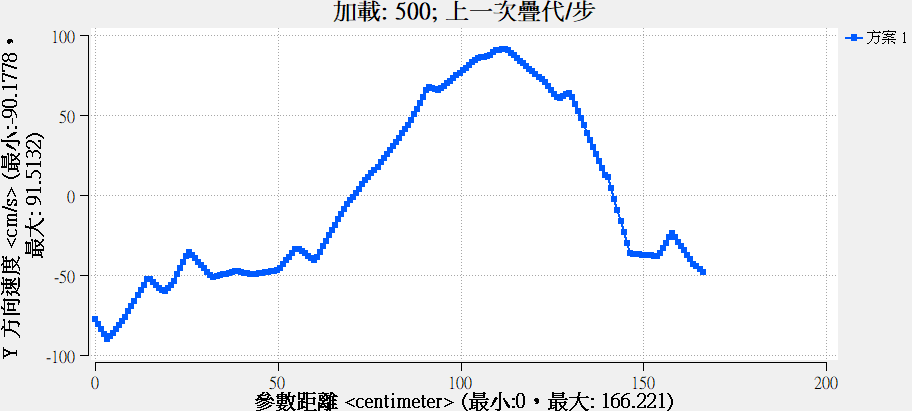
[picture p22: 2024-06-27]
3D_CAD_Drawing/圖檔/DesignVer2_encoder_MG996/ground_support/Y.bmp

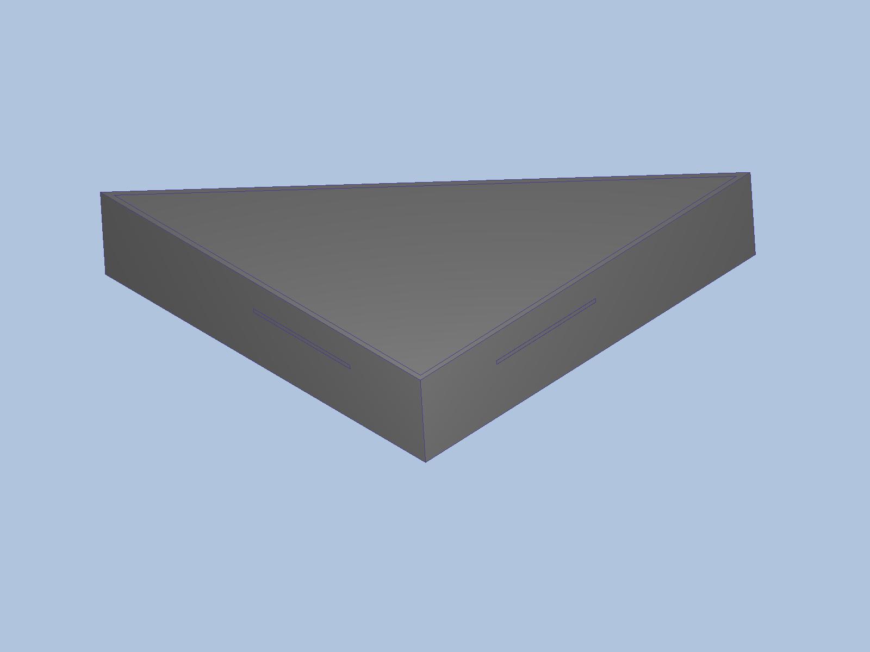
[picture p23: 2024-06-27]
3D_CAD_Drawing/圖檔/DesignVer2_encoder_MG996/ground/preview.jpg

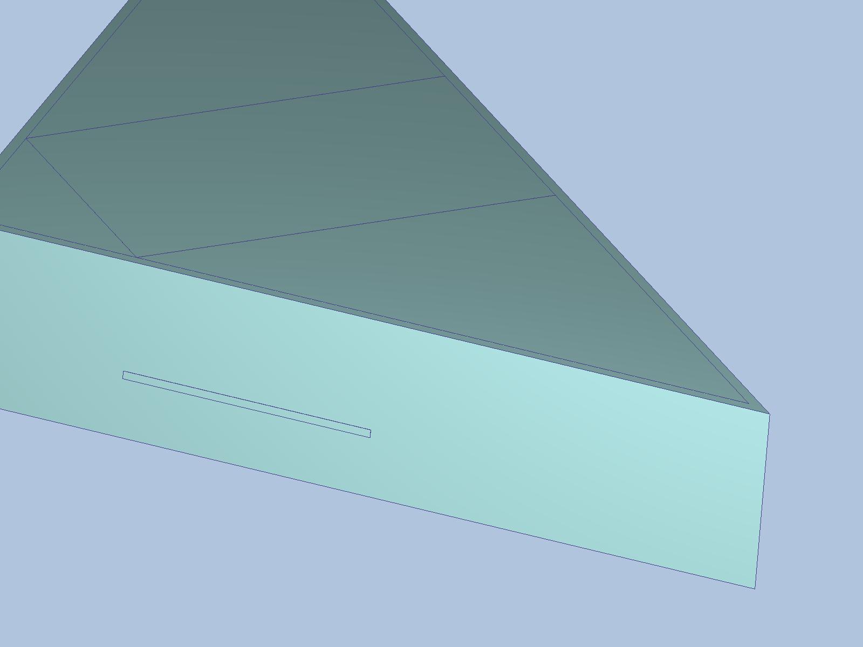
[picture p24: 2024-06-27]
3D_CAD_Drawing/圖檔/DesignVer2_encoder_MG996/ground_support/preview.jpg

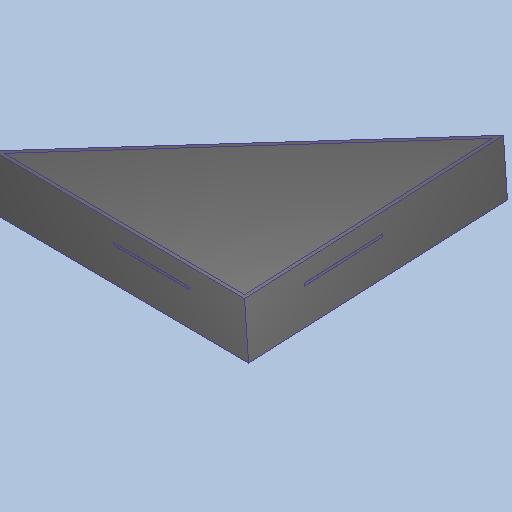
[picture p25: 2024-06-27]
3D_CAD_Drawing/圖檔/DesignVer2_encoder_MG996/ground/設計 1/方案 1/thumbnail.jpg

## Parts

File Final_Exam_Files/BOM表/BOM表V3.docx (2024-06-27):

Bill of Materials

組別 | 26

項次編號 | 零件名稱 | 來源 | 數量 | 單價 | 金額
1 | 9V電池盒 | 祥昌電子 | 1 | 12 | 12
2 | 免焊接 DC插頭 | | 1 | 8 | 8
3 | 18650 電池盒 | | 1 | 70 | 70
4 | 18650鋰電池 | | 4 | 90.25 | 361
5 | Arduino Uno R3 | 蝦皮拍賣https://shopee.tw/jmaker | 1 | 285 | 285
6 | 開關 | | 1 | 4 | 4
7 | 麵包板 | | 2 | 40 | 80
8 | MPU6050 IMU | | 1 | 90 | 90
9 | 光遮斷器模組 | 今華電子 | 2 | 40 | 80
10 | 杜邦線 | | 33 | 1.375 | 45
11 | MG996r 伺服馬達 | | 2 | 180 | 360
12 | SG90伺服馬達 | | 4 | 70 | 280
13 | LM-2596降壓模組 | | 1 | 140 | 140
14 | 9V電池 | 金興發生活百貨 | 1 | 119 | 119
15 | 轉盤滑軌鋼珠 | 蝦皮拍賣https://shopee.tw/angusbao0403 | 10 | 0.1 | 1
16 | M2螺帽 | 實作中心 | 3 | 1 | 3
17 | M3螺絲 | | 3 | 1 | 3
18 | M3螺帽 | | 2 | 2 | 4
19 | M3螺絲 | | 2 | 1 | 2
20 | M4螺帽 | | 8 | 2 | 16
21 | M4螺絲 | | 8 | 1 | 8
22 | 支撐側板 | 課程提供 | 6 | 2 | 12
23 | 支撐圓盤 | | 2 | 2 | 2
24 | 夾層橫板 | | 3 | 3.5 | 7
25 | 小轉盤 | | 4 | 0.5 | 2
26 | 大轉盤 | 課程提供 | 3 | 0.5 | 2
27 | 底板 | | 1 | 12 | 12
28 | 桅杆 | | 1 | 30 | 30
29 | 主風帆 | | 1 | 1 | 1
30 | 次要風帆 | | 2 | 1 | 2
31 | 次風帆馬達支架 | | 2 | 1 | 2
32 | 開帆馬達支架組 | | 1 | 4 | 4
33 | 次風帆轉軸 | | 2 | 30 | 60
34 | 轉盤滑軌 | | 1 | 30 | 30
35 | 牛眼輪 | | 4 | 75 | 300
| | | | 總金額 | 2437

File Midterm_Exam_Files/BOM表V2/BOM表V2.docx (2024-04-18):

Bill of Materials

組別 | 26

項次編號 | 零件名稱 | 來源 | 數量 | 單價 | 金額
1 | 18650鋰電池 | 祥昌電子 | 4 | 90.25 | 361
2 | 銅柱 | | 4 | 3 | 12
3 | 免焊接 DC插頭 | | 1 | 8 | 8
4 | 9V電池盒 | | 1 | 12 | 12
5 | L298N馬達驅動模組 | 蝦皮拍賣https://shopee.tw/jmaker | 1 | 80 | 80
6 | Arduino Uno R3 | | 1 | 285 | 285
7 | 開關 | | 1 | 4 | 4
8 | 麵包板 | | 1 | 40 | 40
9 | 直流馬達及編碼器 | 蝦皮拍賣https://shopee.tw/pizgchen | 1 | 285 | 285
10 | 18650鋰電池盒 | 今華電子 | 17 | 70 | 70
11 | 杜邦線 | | 1 | 1.375 | 23
12 | 9V電池 | 金興發生活百貨 | 1 | 119 | 119
13 | M3螺帽 | 實作中心 | 4 | 2 | 8
14 | M3螺絲 | | 6 | 1 | 6
15 | M4螺帽 | | 8 | 2 | 16
16 | M4螺絲 | | 8 | 1 | 8
17 | 支撐側板 | 課程提供 | 6 | 2 | 12
18 | 支撐圓盤 | | 1 | 2 | 2
19 | 夾層橫板 | | 2 | 3.5 | 7
20 | 下層轉盤 | | 1 | 0.5 | 2
21 | 上層轉盤 | | 1 | 0.5 | 2
22 | 小轉盤 | | 3 | 1 | 3
23 | 馬達左右固定板 | | 1 | 1 | 1
24 | 馬達左右連接板 | | 1 | 1 | 1
25 | 螺絲支架 | | 2 | 0.5 | 1
26 | 底板 | 課程提供 | 1 | 12 | 12
27 | 插銷 | | 12 | 0.83 | 1
28 | 桅杆 | | 1 | 30 | 30
29 | 風帆 | | 1 | 1 | 1
30 | 牛眼輪 | | 4 | 75 | 300
| | | | 總金額 | 1712

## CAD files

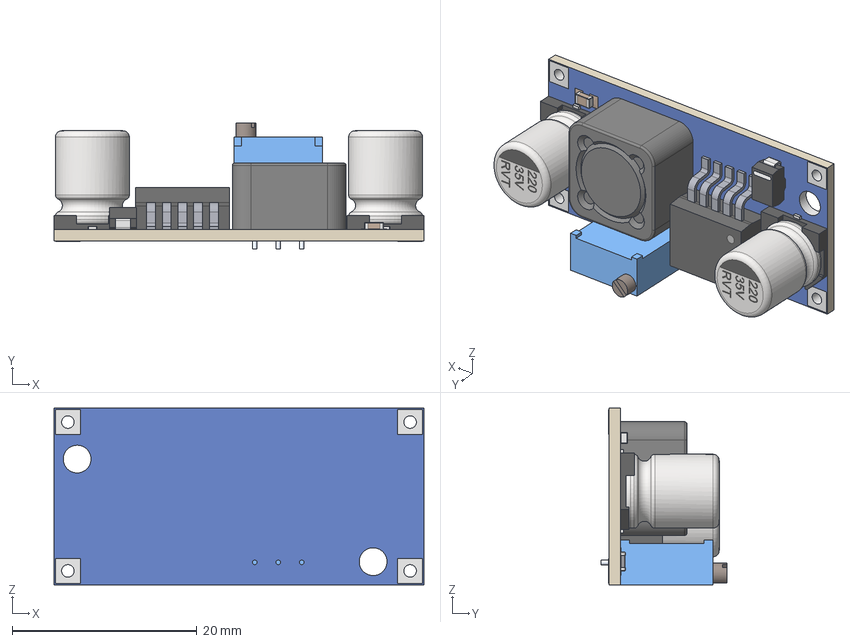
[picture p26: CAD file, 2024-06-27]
3D_CAD_Drawing/圖檔/機電設備/lm2596-dc-dc-buck-converter-module-2.snapshot.9/LM2596 DC-DC Buck Converter Module.stp
40.0 x 13.7 x 19.1 mm
CAPSMD220-35 x 2
Diode SMA
solder_hole x 4

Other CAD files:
3D_CAD_Drawing/圖檔/DesignVer2_encoder_MG996/side_motor.dwg
3D_CAD_Drawing/圖檔/DesignVer2_encoder_MG996/20240412_2.dwg
3D_CAD_Drawing/圖檔/DesignVer2_encoder_MG996/20240412.dwg
3D_CAD_Drawing/[Midterm]Design/Base_final.ipt
3D_CAD_Drawing/[Midterm]Design/DesignVer2.iam
3D_CAD_Drawing/[Midterm]Design/DesignVer_Mid.iam
3D_CAD_Drawing/[Midterm]Design/Lower_Bar.ipt
3D_CAD_Drawing/[Midterm]Design/M4螺帽.ipt
3D_CAD_Drawing/[Midterm]Design/M4螺栓.ipt
3D_CAD_Drawing/[Midterm]Design/OldVersions/DesignVer2.0008.iam
3D_CAD_Drawing/[Midterm]Design/OldVersions/M4螺帽.0001.ipt
3D_CAD_Drawing/[Midterm]Design/OldVersions/[3DP]back_cir_hold_final.0001.ipt
3D_CAD_Drawing/[Midterm]Design/OldVersions/[3DP]bar.0009.ipt
3D_CAD_Drawing/[Midterm]Design/OldVersions/[Midterm]Design.0021.iam
3D_CAD_Drawing/[Midterm]Design/OldVersions/back_down_hold.0005.ipt
3D_CAD_Drawing/[Midterm]Design/OldVersions/m4螺栓.0001.ipt
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

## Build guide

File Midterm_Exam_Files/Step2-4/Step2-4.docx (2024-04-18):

4. Steering and Unfolding Mechanism Overview: Present a detailed explanation of how your steering or unfolding mechanism can harness wind energy to aid in vehicle navigation.
a. Showcase the mechanism's design and operational principles.
b. Clarify how the mechanism contributes to vehicle control.
c. Evaluate the mechanism's current performance and suggest potential enhancements or modifications for the future.

a.

展開機構如圖2-4-1所示，由馬達、桅杆及風帆組成，馬達的功能為提供桅杆轉動所需的動力，風帆的功能則為增加受力面積。

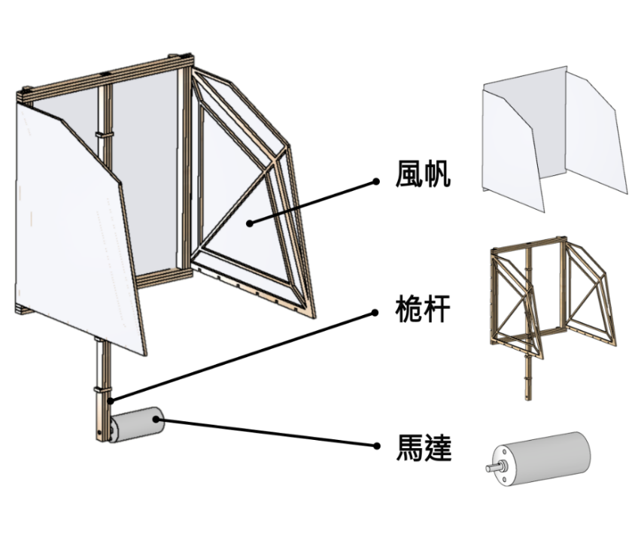
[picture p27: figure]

圖2-4-1、展開機構

該機構的運作原理是馬達會將桅杆帶動到最高點，再透過風帆盡可能地汲取風的推力，因為馬達的角度控制是機構能否成功的關鍵，所以本組將該馬達搭配微控制器、編碼器與馬達驅動模組組成PID負回饋控制系統，如圖2-4-2所示，來精確地控制馬達軸旋轉到目標角度。

運作時，與馬達軸連接的編碼器將不斷向微控制器發送資料，微控制器再以該資料推得馬達軸的當下角度，並藉由比較其與目標角度的差和 k_p 、 k_i 與 k_d 的值來輸出PWM與轉向訊號給馬達驅動模組，透過其來供給馬達足夠的電壓和調整當下的轉速和轉向，最終，讓馬達軸旋轉到目標角度。

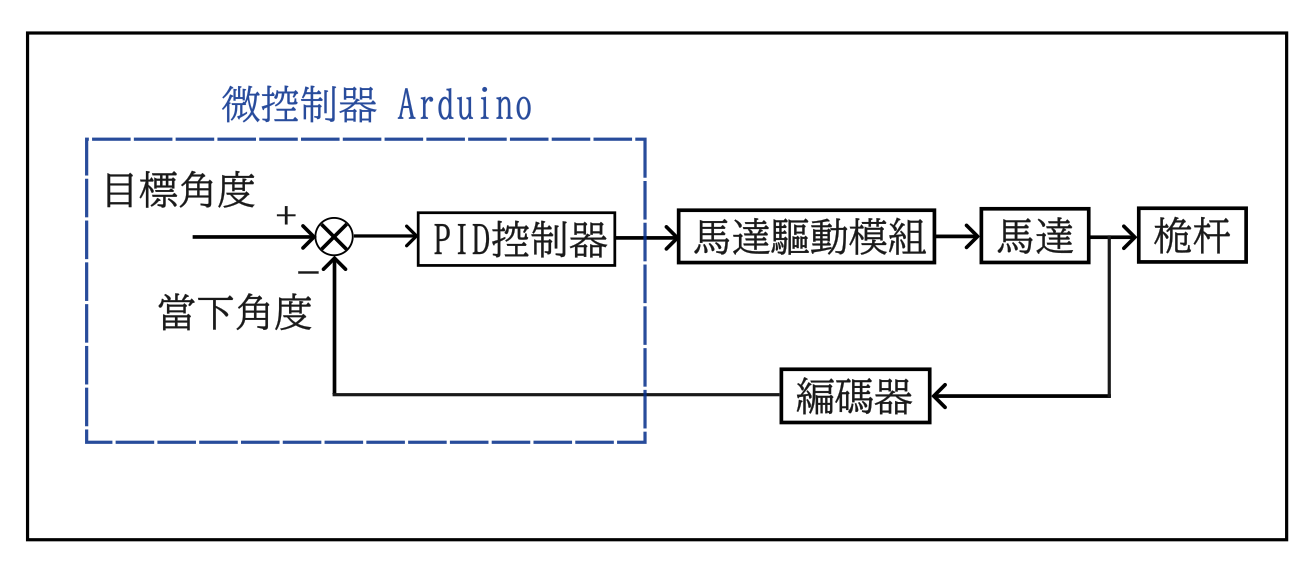
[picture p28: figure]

圖2-4-2、Block diagram

在初期將微控制器接上電腦測試無負荷的狀況時，上述的PID負回饋控制系統在將 k_p 設定為1.45的情況下，成功地在0.6秒內將馬達旋轉了90度，並穩定了下來，如圖2-4-3所示。

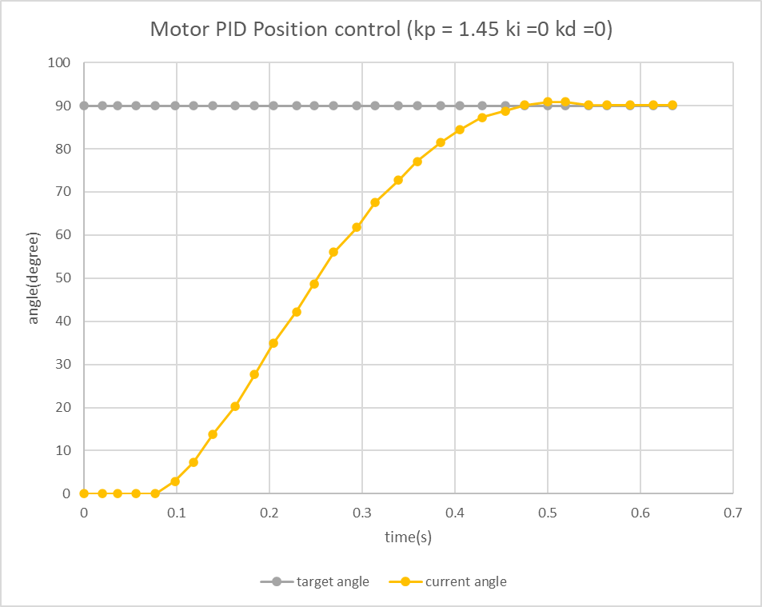
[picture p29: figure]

圖2-4-3、馬達PID角度控制

而實際情況，馬達最後會在會 k_p 為2.45、 k_i 與 k_d 皆為0的情況順利帶動桅杆順時針轉動160度，讓桅杆升到最高點並與地面保持垂直，如圖2-4-4及圖2-4-5所示。

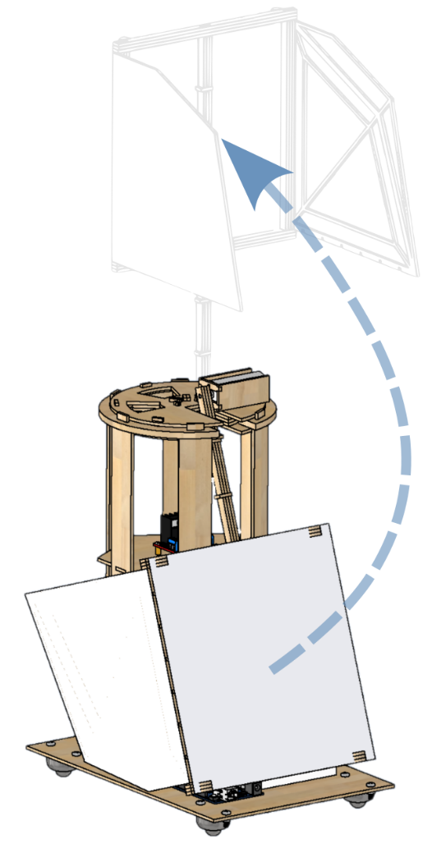
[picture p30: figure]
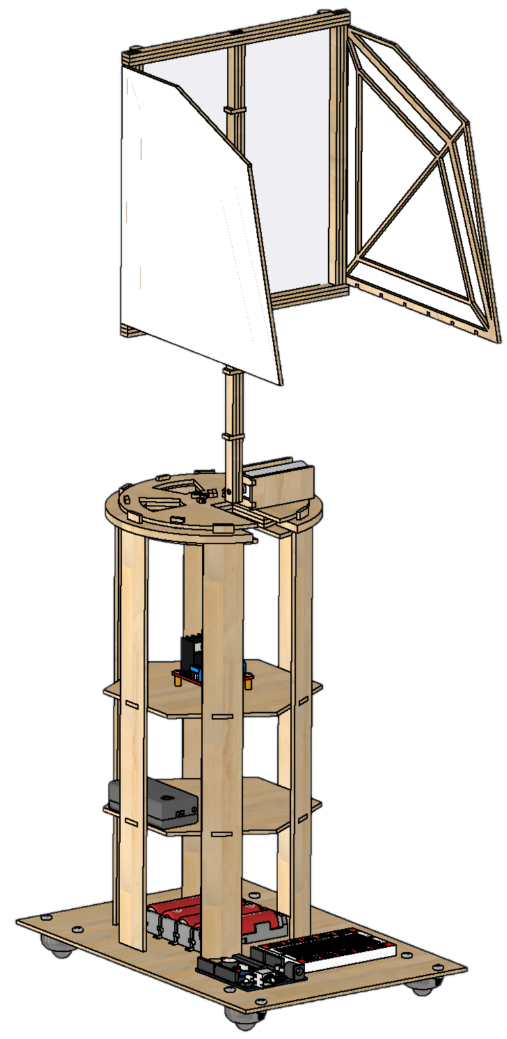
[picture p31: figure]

圖2-4-4、展開過程示意圖 | 圖2-4-5、完整展開圖

b.

該展開機構會將風帆升到約50到70公分的高度，因而可阻攔約在60公分處的風，周圍的空氣分子也因此在風帆的受風面產生高壓區，風帆的背風面產生低壓區，兩區的壓力差與風帆面積積分後算出的推力，將推動風帆帶動車子往風帆的背風面前進，因而能控制車子的前後方向。

c. Evaluate the mechanism's current performance and suggest potential enhancements or modifications for the future.

該機構的表現能分為風帆效能和馬達控制兩個部分評估。

風帆部分，在馬達有將桅杆上升到最高點的情況下，每次測試階段都能跑到終點，但所花時間仍然不太穩定，主因是若車子因牛眼輪或風所造成的推力發生偏轉，就只能靠風帆左右兩側的其中一側得到推力，但由於其面積相對中間的帆來得小，而造成須花較多時間來前進，因而風帆效能的部分仍有待加強。

要改善上述的風帆效能，未來可考慮用伺服馬達張開左右兩側的風帆來增加受力表面積，並使用陀螺儀偵測車子偏轉角度，再根據偏轉程度來調整伺服馬達的角度，使車體能再被風的推力轉正，以改善偏轉問題，並讓風帆效能有進一步的提升。

馬達部分，雖然每次放下車子的位置不同都會造成操作環境的稍許變動，但在調整完PID參數後，幾乎測試時都能以肉眼觀察到桅杆有上升到最高點，因而馬達控制的部分在現階段仍不用太擔心。

但考慮到未來要增加帆及伺服馬達的情況下， k_p 勢必只能調大，若有觀察到轉動時有過衝、穩態誤差過大或震盪情況發生時，將根據表2-4-6調整 k_i 與 k_d 來使馬達轉動情形得到改善。此外，由於無另外添購無線通訊的電子元件，目前仍只能在接電腦的情況下，測得馬達的當前角度與目標角度，因而可在期末測驗前考慮加裝通訊設備或其他方法來測得馬達在賽道上的實際轉角。

圖2-4-6 PID參數調整方法表

調整方式 | Rise time | Overshoot | Settling time | Steady state error | Stability
k_p 增加 | 減少 | 增加 | 小幅增加 | 減少 | 變差
k_i 增加 | 小幅減少 | 增加 | 增加 | 大幅減少 | 變差
k_d 增加 | 小幅減少 | 減少 | 減少 | 變動不大 | 便好

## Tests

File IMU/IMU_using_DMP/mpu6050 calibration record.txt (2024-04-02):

mpu6050 calibration record

1000 counts
accel_offset_xyz: 5.76   -0.61	13.33
gyro_offset_xyz: -1.85	-1.19	1.62
1000 counts
accel_offset_xyz: -26.50   -0.84   20.64
gyro_offset_xyz: 1.62	1.29	1.42

3000 counts
accel_offset_xyz: -11.91   4.95   22.56
gyro_offset_xyz: 0.86   0.77   0.67
3000 counts
accel_offset_xyz: -13.54   -10.52   22.41
gyro_offset_xyz: 0.94   0.71   0.70

5000 counts
accel_offset_xyz: -11.86   -8.03   31.16
gyro_offset_xyz: 0.80   0.73   0.77

20000 counts
accel_offset_xyz: -23.19   -4.63   19.49
gyro_offset_xyz: 0.65   0.72   0.62

MPU6050 connection successful

Reading sensors for first time...

Calculating offsets...
...
...
...
...

FINISHED!

Sensor readings with offsets:	-4	-7	16383	0	0	0
Your offsets:	147	-1793	1409	98	-4	124

Data is printed as: acelX acelY acelZ giroX giroY giroZ
Check that your sensor readings are close to 0 0 16384 0 0 0
If calibration was succesful write down your offsets so you can set them in your projects using something similar to mpu.setXAccelOffset(youroffset)

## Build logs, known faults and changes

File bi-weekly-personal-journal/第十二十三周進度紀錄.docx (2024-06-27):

Bi-weekly Personal Journal

Name: 林士程 | Group: 第26組 | Role: 機電系統控制

Objectives

討論出優先度較高或確定要使用的機電系統元件，並大致規劃其用途。畫出上述元件的線路連接圖。

Summary of Outcomes

-Task 1:

目前初步規劃將使用Arduino Uno R3來當作微處理器，讀取MPU-6050量測到的三軸加速度值和角速度值，解碼出編碼器的AB相數位訊號，以推算出直流馬達的角位移量，並透過馬達驅動模組L298N控制其轉動。

-Task 2:

Arduino Uno R3的主要用途，為透過I2C接口讀取MPU-6050的訊號，和輸出PWM訊號以控制馬達。

MPU-6050其主要用途為當測量到的向下加速度高於一定值時，觸發風帆展開，次要用途為量測目前車體的三軸角度。

25GA-370整合了直流馬達、齒輪箱和編碼器為一個模組以方便使用，其兩項主要用途為控制風帆的展開和調整風帆的轉向。

L298N的主要用途為驅動25GA-370轉動，次要用途為提供微處理器供電，但這部分考慮到可能會因微處理器端阻抗不夠高而影響直流馬達的轉動，可能會另外加buffer提高阻抗或不使用其供電，直接獨立直流馬達和微處理器的電源。

-Task 3:

元件的線路圖大致如下圖，作為實際接線路的參考，此處微處理器未使用電池，因為之後測試時應該會直接用usb線供電和燒錄程式編譯碼。

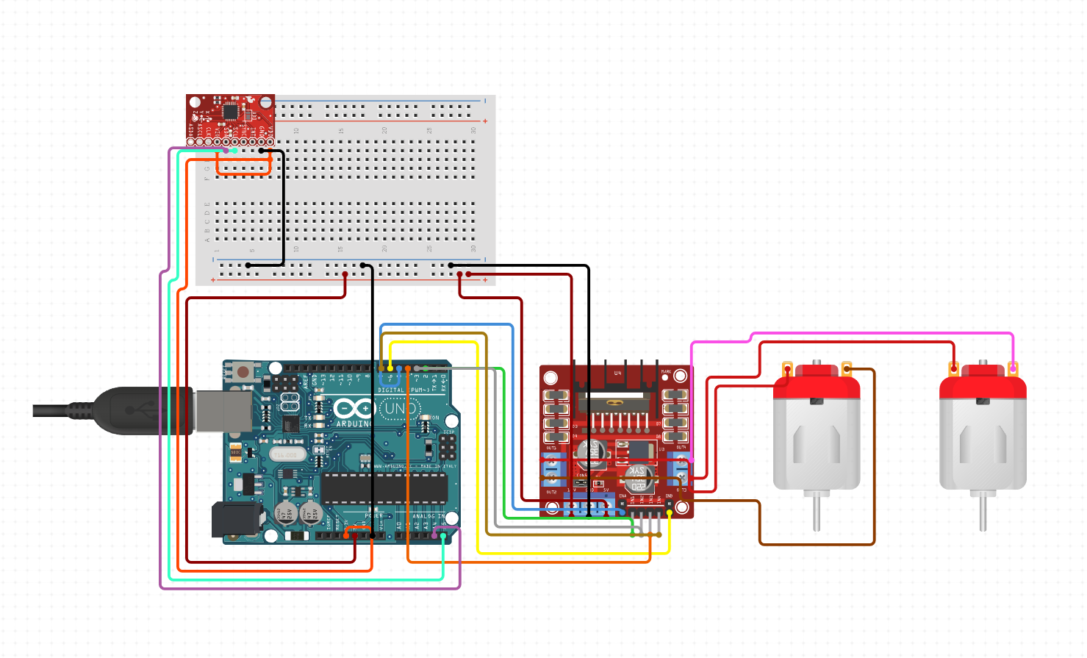
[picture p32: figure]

Issues and Challenge

- Challenge 1:

目前只能大致預估風帆的重量和長寬，因而在挑選直流馬達時只能大概選用較大的扭矩量來避免扭矩不夠。

- Challenge 2:

目前還不確定要不要使用編碼輪，若使用的話可能可以完全取代MPU-6050的功能，這部分希望可以等聽過第五周的課再做考量，但目前認為用編碼輪有可以完整的確定車體在車道上的位置的優勢，這是加速度計相對無法做到的。

Perspectives

之前在社團就有稍微碰過編碼器和馬達相關了，但相對來說陀螺儀和加速度計就沒什麼經驗，這次是第一次使用，也藉由這次機會，了解了其腳位接法、供電電壓限制、原理和其局限性。

Plans for Next Week

- Perspective 1:

Challenge 1應該還是要等到機構那邊稍微設計完，或是測量完帆和密集板的重量才能稍微估算出來，規劃上來說可能要到下幾周才能達成。

- Perspective 2:

Challenge 2如上所述，希望聽完第五周的課後再來做決定，會在下一次的日記呈現。

- Perspective 3:

鑒於上述的問題可能都要等到第五周才能解決，我決定下周先在網路上找和寫一下之前沒碰過的MPU-6050的程式庫和程式。

Remarks

因為目前只決定用MPU-6050，所以編碼輪的部分在上述沒有提很多，但這應該還是專題相關的，所以想在這邊提一下目前的想法，如果要確立車體在車道上的位置，至少要有兩顆分別量測x和y方向的位移量，但這樣一來就必須將其固定在一定方向，這必定會增加摩擦力使車體行進距離變短。但若能確立車體位置，並透過流場模擬軟體來決定風帆在哪裡轉向能得到最大的推力，感覺對車子行進應該還是利大於弊。

Objectives

搜索MPU-6050相關的程式庫，並利用其寫讀取三軸加速度值和角速度值的程式。

Summary of Outcomes

-Task 1:

目前找到了由Adafruit和Jeff Rowberg提供的MPU-6050相關程式庫。

-Task 2:

Adafruit的可以由其提供的範例，可以用其程式庫的函式直接定義陀螺儀和加速度計的測量範圍，還可以選擇濾波器頻寬來濾除雜訊，並可直接讀取三軸加速度值和角速度值。

Jeff Rowberg的就相對複雜，這部分我直接參考了網上的教學影片和MPU-6050的DATASHEET，來學習如何透過I2C將它從Sleepmode喚醒，定義陀螺儀和加速度計的測量範圍，和取得三軸加速度值和角速度值。

Issues and Challenge

- Challenge 1:

這周花最久理解的部分都是理解別人寫的程式的部分，畢竟沒有一些先備知識，只有計算機程式學到的一些c語言基礎，所以一開始看到Wire.write()內的16進制的代碼不知道是什麼意思。

- Challenge 2:

也是程式理解的部分，Wire.read()<<8 | Wire.read() 當中的bitwise shift operator

和bitwise or operator，要查才知道其運作原理。

Perspectives

學到I2C的通訊方法，能透過DATASHEET上提供的register 16進制代碼用Wire.write()寫入數據，改變MPU-6050的各項參數或讀值等功能。也學到了如何透過bitwise operator快速地將兩個8bit的值合併成一個16bit的值。

Plans for Next Week

- Perspective 1:

因為MPU-6050很容易受雜訊干擾，網路上是推薦用卡爾曼濾波算法來濾波，可以稍微研究看看，但若太過複雜可以考慮直接用Adafruit的寫好的濾波函式就好。

- Perspective 2:

下禮拜應該就會拿到MPU-6050，將實際利用這周寫好的兩個程式測量三軸加速度值和角速度值，並且利用角加速度值計算三軸傾角。

- Perspective 3:

利用上學期量測原理的客參考網路上的教學影片寫的程式，寫出透過編碼器測量馬達的角位移量的程式。

Remarks

這周基本上都在處理跟程式相關的，想到剛好之前有碰過Git和GitHub一下，所以趁這個機會順便建了一個專門處理這次實務專題的remote repository，來方便之後用筆電拿程式資料和測試，或許下次開會能跟組員分享一下，但感覺google cloud共編和excel還是蠻方便地，另外，也順便看了一下之前沒學的branch方面，結果看了之後的心得是好像用不到哈哈，畢竟程式量也不是那麼大，add、commit、push和pull應該就很夠用了，也順便複習Markdown的語法來寫README，雖然還是不太知道要寫啥，之後再說吧。GitHub網址：rumsey000/Practice-of-Mechanical-Engineering (github.com) (https://github.com/rumsey000/Practice-of-Mechanical-Engineering)。

Objectives 實際利用這周寫好的程式測量三軸加速度、角速度和傾角值;寫好使用編碼器測量馬達角位移量的程式，並透過其值控制馬達。

Summary of Outcomes

-Task 1:

使用上週找到的由Jeff Rowberg開發的開源程式庫，來讀取MPU-6050的三軸加速度、角速度和傾角值，圖1為實際測試的資料畫面，直接以serial monitor呈現。

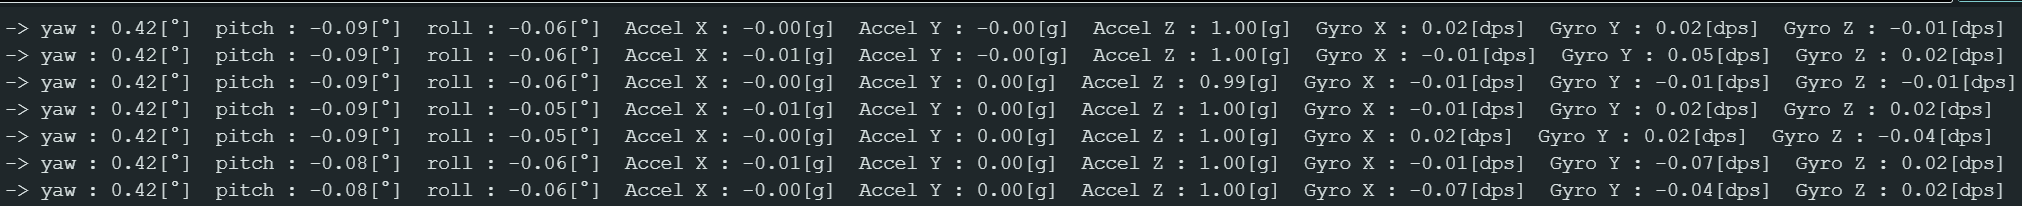
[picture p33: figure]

圖1、MPU-6050的資料讀取

-Task 2:

對讀取的資料進行分析確認應需使用何種校正。靜置時尚未經單位轉換的加速度及角速度值如圖2所示，皆始終有小幅度的抖動，因而須採取另外撰寫校正程式的方式，透過加總一定次數內的單次誤差量取得總誤差，再將其除以總次數以估算誤差平均值，來校正加速度及角速度值。傾角值則如圖3所示，在一定時間內，會到達穩態，因而直接以其值來做校正。

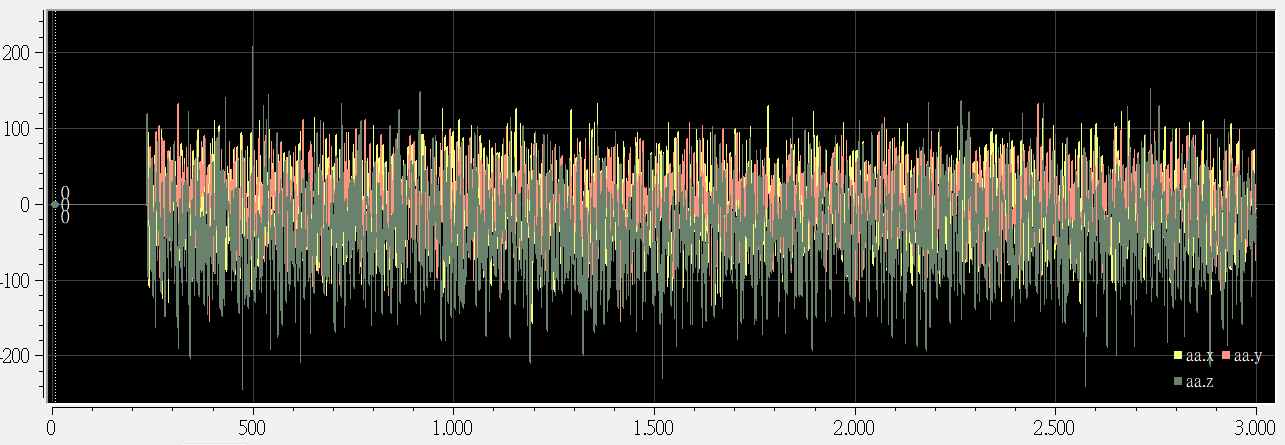
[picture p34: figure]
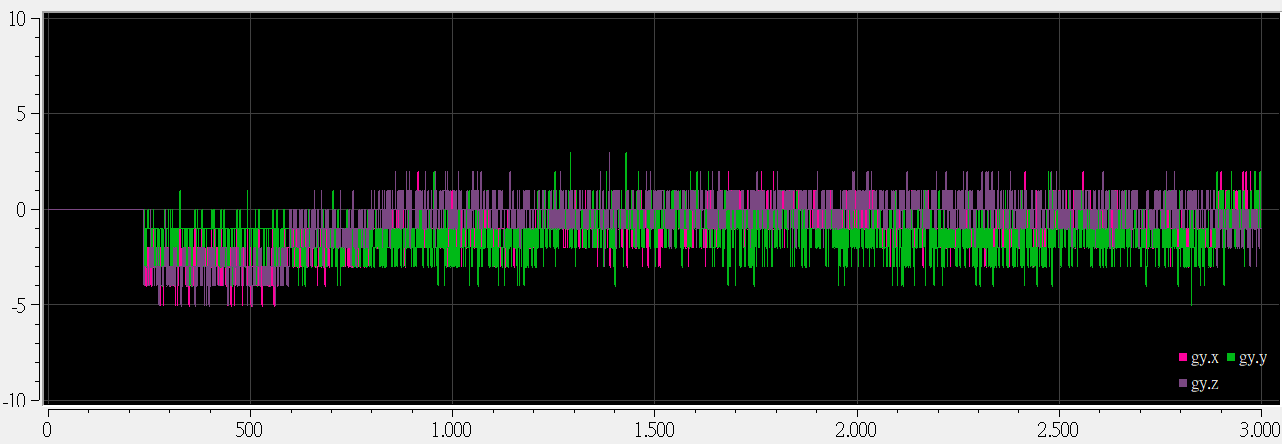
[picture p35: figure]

圖2、加速度及角速度對資料

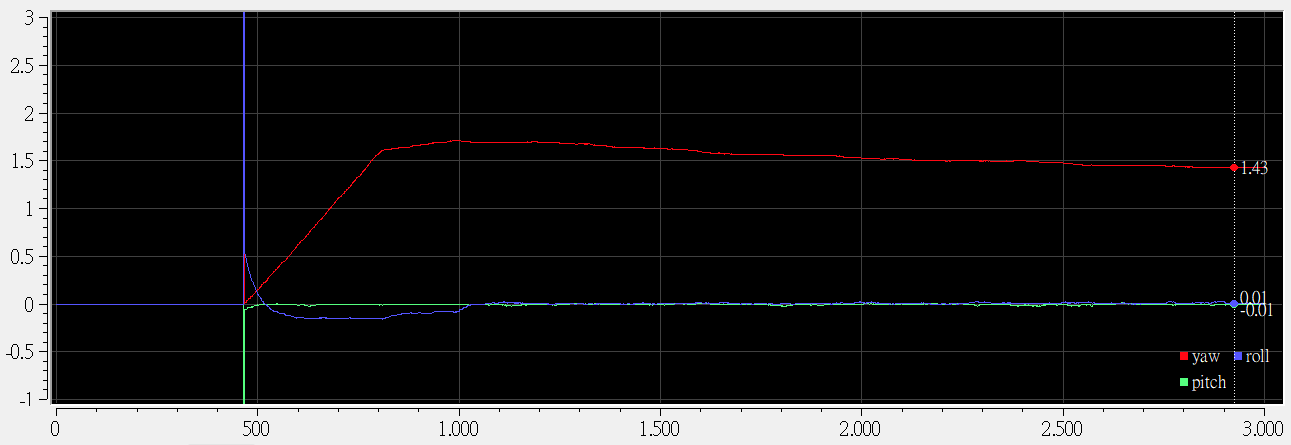
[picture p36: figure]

圖3、傾角值對資料點圖

-Task 3:

將編碼器、麵包板及Arduino板的線路接好，寫好使用編碼器測量馬達角位移量的程式，並先透過手轉編碼器來確認角位移量讀值正確。

-Task 4:

將馬達、馬達控制器、電池、麵包板及Arduino板的線路接好，先以PWM驅動馬達，確認轉速功能和程式控制的正反轉功能正常，再透過Task 3量測到的讀值來做PID控制，讓馬達旋轉90度，圖四為測試結果。

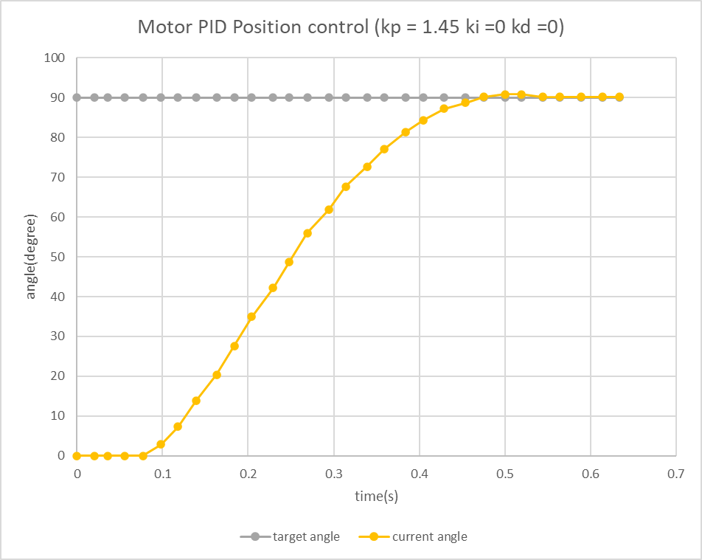
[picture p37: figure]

圖4、PID控制角度對時間圖

Issues and Challenge

- Challenge 1:

測試時發現MPU6050在開始運作時期其X軸和Y軸構成的平面必須平行於地面才能讀到正常的值

- Challenge 2:

Jeff Rowberg的程式庫使用程式儲存空間使用率已達50%，若之後期末的程式量較大，可能無法負荷。

- Challenge 3:

若使用serial monitor讀編碼器值時會在開始時出現中途斷電的現象，導致測試不易。

- Challenge 4:

若PWM值設太低會造成電壓不在馬達的工作電壓範圍內，無法順利轉動馬達。

- Challenge 5:

以PID追角度時，將馬達放在桌上和以手抓住時，能跑到的角度不同，需重新設kp、ki及kd值才能重新追到90度。

Perspectives

學習到馬達驅動器的內部電路構造，例如H橋的邏輯閘和電晶體開關是如何同時控制馬達的轉速和轉向，及線路接法。學會編碼器的資料讀取和利用程式、解析度及齒輪減速比將其轉換為馬達角位置的方法。將自動控制的PID控制實際應用到馬達位置控制。

Plans for Next Week

- Perspective 1:

寫只用I2C的通訊讀加速度及角速度和傾角的程式，而不使用Jeff Rowberg直接使用MPU6050內建DMP來處理資料的方法。

- Perspective 2:

寫校正程式來校正MPU6050加速度及角速度量。

- Perspective 3:

改換SerialPlot軟體來讀取編碼器資料。

- Perspective 4:

加上開關來控制何時要運行馬達部分的程式。

Remarks

這周上課時，機電課程介紹了測程法，才知道前面提到的那種方法不可行，因為編碼輪不能測走，而應使用兩顆編碼輪，將其轉動角度差透過矩陣換算為車子轉動角度，目前覺得這可能會是期末測試時需用上的，組員也建議我試試用加速度計來測距離，但礙於時間因素，仍未動工。

上週原定的目標是用編碼器讀值而已，但組員說想測一下連接件在馬達運轉時的穩定度才把目標稍微變更。

Objectives

寫出校正程式來校正MPU6050的加速度及角速度量，撰寫用開關來控制何時要運行馬達部分的程式。

Summary of Outcomes

-Task1:

校正完MPU6050的加速度及角速度量，總次數2000的程式及結果如圖1所示。

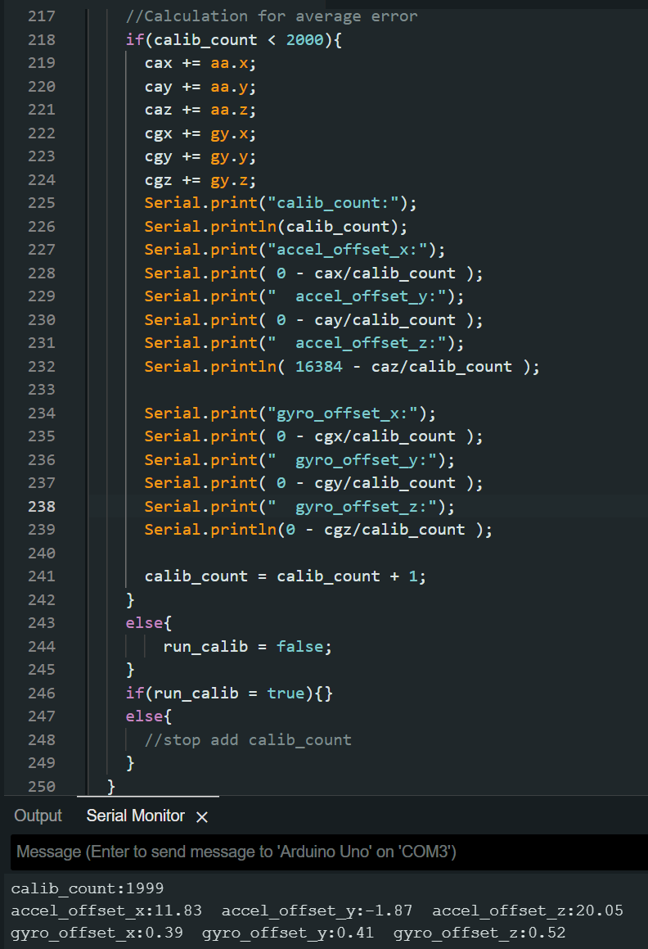
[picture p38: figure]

圖1、校正程式及校正結果

-Task 2:

寫完開關程式，來控制馬達何時轉動，並透過Pin13的LED燈來確認狀態。

Issues and Challenge

- Challenge 1:

由於目前手邊只有復位式的開關，所以我先讓來自Arduino並通過開關的5V或因為開關不通而接地的0V代表高低電位，再使用attachInterrupt()函式來讀高低位變化，當它由高變為低電位時，才將另一自訂布林參數反向，並以此值決定是否運行馬達。但實際操作時發現有時太快按下再放開時，卻無法停下馬達或執行馬達部分的程式。

Perspectives

開關的程式及接線使用方法，並知道上拉電阻和下拉電阻目的在於避免電位處於float

的狀態隨環境上下跳動而無法讓其依開關保持在高或低電位，及其電路圖原理，並且由於arduino每個腳位都有內建電阻，因而能直接用pinMode(BUTTON_PIN, INPUT_PULLUP)來直接使用，不須再另外接10k電阻。

Plans for Next Week

- Perspective 1:

研究上述Challenge 1所提及的問題並試著解決。

- Perspective 2:

繼續撰寫只用I2C的通訊讀加速度及角速度和傾角且程式儲存空間使用率較低的程式。

- Perspective 3:

試著撰寫通過加速度計來測距的程式並做實際距離和測量距離比較圖。

Remarks

之前都是用9V電池來驅動馬達，但之後那顆應該會拿來供Arduino板電，馬達應該會換電壓再高一點的電池來驅動，到時PID參數還要再調，如果順利的話應該會跟機構那邊一起測負重時的轉速狀況。

Objectives

找出並解決上週Challenge 1的開關彈跳問題，寫完程式儲存空間使用率較低的IMU程式。

Summary of Outcomes

-Task 1:

上週所遇問題經研究是開關的「彈跳」現象，經由加入Debounce的程式以軟體解決這項問題了。

-Task 2:

寫完上周所提及的程式儲存空間使用率較低的IMU程式並校正。

Issues and Challenge

- Challenge 1:

上網蒐集開關的問題後，發現是大部分開關的常見問題，由於在按下和放開開關時，接觸點可能會因衝力與彈力一起作用下，發生連續好幾次的接觸、斷開現象，通常稱此現象為「彈跳」。

- Challenge 2:

先寫好從I2C讀取角速度和加速度後，這兩項值是沒問題的，但只使用角速度或加速度來推傾角變化的話，會有明顯的誤差產生。

Perspectives

要解決談彈跳問題可以用硬體方式，例如我自己在機電系統原理的課上剛好有學到的SR flip-flop以邏輯閘來解決，或軟體方式，這次使用的即是這種，直接使開關確認到剛開始切換時，不要讀取一定時間內的電壓值，這段時間後確認開關有切換後，再反轉指定的變數狀態。

上網查了以後，發現大部分IMU通常都會融合陀螺儀和加速規的資料來透過卡爾曼濾波器來融合這兩項資料求得傾角，因而我直接使用卡爾曼濾波器的相關開源程式庫來求得較準確的傾角。

Plans for Next Week

- Perspective 1:

將馬達的程式與開關的程式整合在一起，並測試其功能是否正常。

- Perspective 2:

將整合的程式所需的部分程式包成函數，並撰寫期中測驗要使用的主程式。

Remarks

這周討論過後，組內認為IMU期中不太會用到，因為打算以time-based當作控風帆的方式，因此先主要將馬達和開關程式處理好就可以，期末部分，因為有轉向部分，所以可能仍然會用得到。

Objectives

將馬達的程式與開關的程式整合並測試，將部分程式包成函數並撰寫期中測驗要使用的主程式。

Summary of Outcomes

-Task 1:

將馬達的程式與開關的程式整合在一起了，並確認了功能正常，測試內容為按一下馬達轉90度，再按一下馬達暫停，持續這個循環，並確認無彈跳現象發生。

-Task 2:

將馬達部分的程式合併為一項為只有kp、ki、kd和角度參數的函數PIDControlMotor()，開關部分則將讀取與Debounce整合為另一函數ReadAndDebounceBotton()。

-Task 3:

撰寫期中測驗要使用的主程式，主要是以開關或delay()來切換變數state，再以state的狀態決定馬達狀態，並且切換狀態時還會切換LED來提醒使用者，目前設計為按下開關後，停兩秒，在讓馬達轉特定角度，再按一下，即停止，重複這個循環以利期中測試不停錶的要求。

Issues and Challenge

- Challenge 1:

由於目前機構那邊還有點小調整，所以仍不確定馬達要轉幾度，目前只能先大致測一下功能正常。

Perspectives

這周撰寫期中測驗的方法，尤其是state變數來控狀態的方法，其實是從上禮拜網路找的IMU校正程式那邊借鑒過來的，也有點類似另一堂課labview業師講的狀態機，由於我認為這樣寫對讀程式或要臨時改哪個階段的參數也方便，就剛好將學習到的東西實作出來看看。

Plans for Next Week

- Perspective 1:

將部分杜邦線替換成30公分長，並將所有機電設備固定在車子上。

- Perspective 2:

測試馬達接上桅杆的穩定性，調整pid參數及目標角度。

- Perspective 3:

畫好機電設備的工程圖。

Remarks

這周雖然已經寫完了期中需要的程式，但下周就要測的話感覺時間上還是有點趕，或許期末時應該在早個一周開始寫就能這禮拜開始測。

Objectives

將電線延長並把機電設備固定在車子上，及測試調整馬達的PID參數及目標角度。

Summary of Outcomes

-Task 1:

將部分杜邦線替換成30公分長，焊接部分連接到馬達或電池的電線以延長，並將所有機電設備透過泡棉膠、螺絲或銅柱等方式固定在車子上。

-Task 2:

畫好機電設備的工程圖，大部分是從grabcad網站找的3D圖檔。

-Task 3:

測好接上風帆的馬達的PID參數及目標角度160度。

Issues and Challenge

- Challenge 1:

馬達與桅杆的軸以熱熔膠黏不住會空轉，最後透過三秒膠才順利解決。

- Challenge 2:

馬達在轉動時能轉到目標角度，但因風的推力風帆會逐漸往後倒，因而我們在桅杆後方加上擋塊以避免此現象。

Perspectives

學習焊接電線的方法及銅柱的用法，如墊高電路板及避免PCB背板的焊點短路。

Plans for Next Week

- Perspective 1:

先以期中的車跑一次期末測試的場地。

- Perspective 2:

討論應改善或前進的方向。

Remarks

這周檢錄之前，突然發現馬達轉不動，及時測試才找到問題是微控制器壞了，幸好有別組同學願意借我們，才勉強過關，下次測驗前，真的要提找到再檢查有沒有零件的問題和備好可能會壞的電子零件。

Objectives

期末場地預先測試及討論車子整體應改善或調整的機構或控制。

Summary of Outcomes

-Task1:

先以期中的車跑一次期末測試的場地，並討論問題點。

-Task 2:

討論還應增加那些機電設備。

Issues and Challenge

- Challenge 1:

測驗時，發現會微微地撞到草地，並有部分機率輾過去後，再順利達到終點，但若風帆角度在撞到草地後，正對著風的面積太小可能會因而不動，若無正對賽道則會往偏離賽道終點的方向前進而脫離賽道。

Perspectives

目前認為應該先增加風帆的面積來提高風的推力，盡可能避免車子不同的情況發生。

Plans for Next Week

- Perspective 1:

購買新的微控制器及伺服馬達以張開風帆。

- Perspective 2:

撰寫兩顆伺服馬達程式。

Remarks

再增加風帆面積後，就是要處理會撞到草地的問題，及最後轉彎角度的問題，轉彎問題應該原本預計是配合感測器，來控風帆方向但還沒實作，至於撞到草地就還再思考，或許應考慮讓風帆再進入轉彎前不要完全張開風帆，使風的推力變小這個方向來做。

Objectives

買完電子材料及撰寫伺服馬達控制的程式。

Summary of Outcomes

-Task1:

買完Arduino板及兩顆SG90伺服馬達。

-Task 2:

使用Servo.h函式庫來控制伺服馬達的轉動方向和角度。

Issues and Challenge

- Challenge 1:

測試時，伺服馬達轉180度時，通常會少轉大約10度。

Perspectives

學會如何使用函式attach()及write()來控制伺服馬達。

Plans for Next Week

- Perspective 1:

測試利用伺服馬達將風帆張開的機構。

- Perspective 2:

前項測試若穩定度高，再思考轉彎問題如何透過編碼器或陀螺儀感測器解決或單純以time-based解決。

- Perspective 3:

風帆轉向控制討論。

Remarks

Challenge 1的問題我想等到實際接上副桅桿測在看看是否需要考慮，因為考量我們的機構只需左右兩張帆都轉90度就能達成張開的目的，或許這項問題只要單純增加角度就能解決了。

Objectives

將伺服馬達連接副桅桿，測試風帆張開與關閉功能，並重新繪製了接線圖。

Summary of Outcomes

-Task 1:

將伺服馬達的舵與3D列印出來的套筒用束帶綑緊，成功使兩顆馬達連接到兩根副桅桿上，如圖1所示，按下開關後，會再5秒後啟動兩顆馬達後，使其各轉90度，並讓風帆展開，如圖2所示，最後再次按下開關後，會讓馬達將風帆關閉，呈現與圖1一樣的狀態。

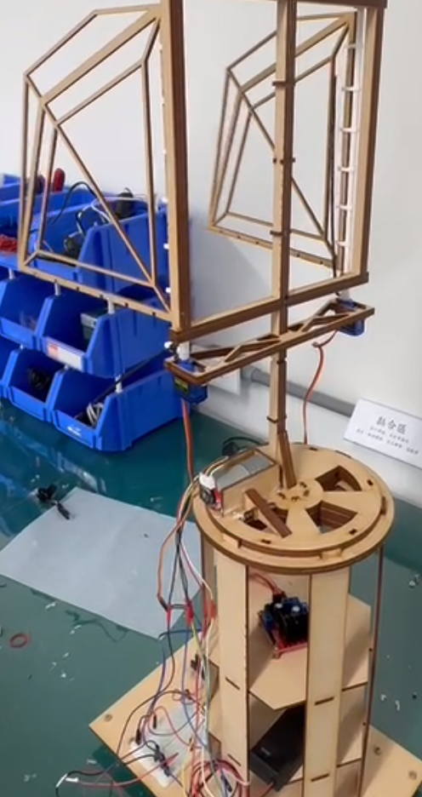
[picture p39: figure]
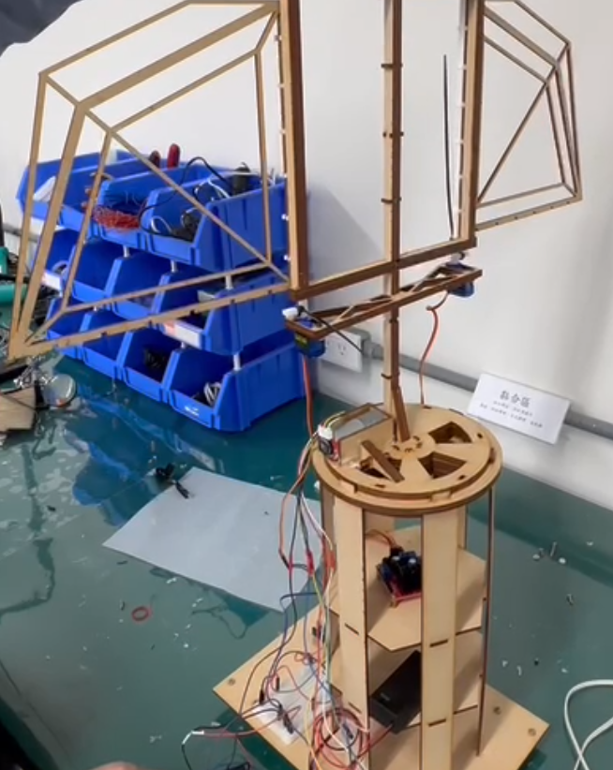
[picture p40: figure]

圖1、馬達連接副桅桿圖 | 圖2、風帆展開圖

-Task 2:

由於目前的電子元件及電線數目逐漸變多，因此我又畫了另一張接線圖，如圖3所示，來幫助我確認電線的接法正確，由於目前的線上軟體都無囊括所有我需要的電子元件，因此我使用Block Circuit EDIT這個線上電路圖繪製軟體來匯入所有電子元件示意圖，再透過其提供的功能完成拉線的圖示。

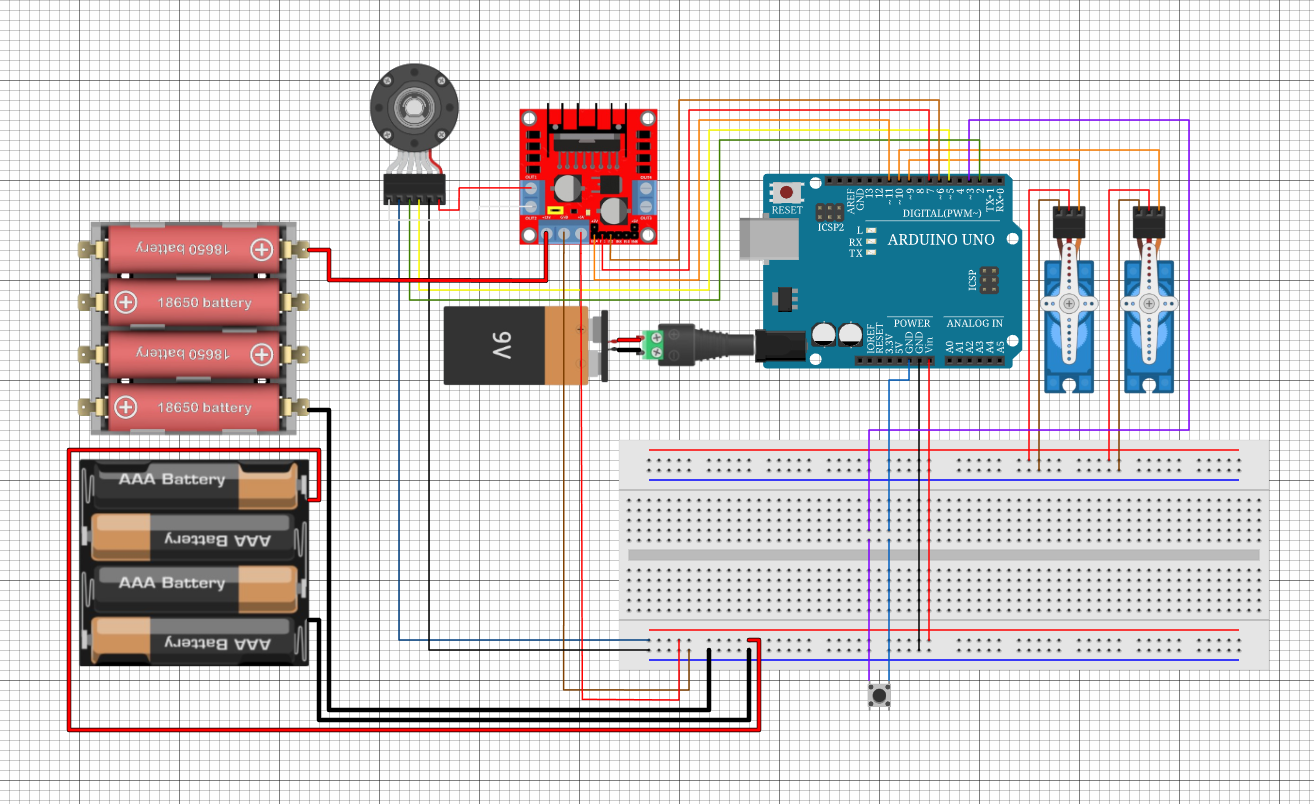
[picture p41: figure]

圖3、元件接線圖

Issues and Challenge

- Challenge 1:

副桅桿的機構由於原本設計圖的錯誤而需重新印一次，且原先風帆的結構也有部分地方快斷裂的感覺，因而須將部分結構重新雷切，因而機構那邊又花了不少時間調整設計和組合風帆。

- Challenge 2:

在上述的Task 1有遇到因馬達轉速過快而使風帆震動太大力的情形，因而除了角度控制外，可能還需加上速度控制。

Perspectives

在上述的Task 1中，我學會了如何使伺服馬達一顆反轉，一顆反轉，由於其只能指定角度，因而我使其中一顆由0度轉到90度，另一顆則從90度轉回0度，即能達成需求。

Plans for Next Week

- Perspective 1:

研究伺服馬達如何調整速度的程式，並實際測試其功能。

- Perspective 2:

研究用來轉動轉盤，帶動風帆轉向的步進馬達的程式。

Remarks

目前感覺每周都有點進度緩慢，組員中還有人在每週五下午原定的上課時間提早離開，實在認為進度有點堪憂。

Objectives

伺服馬達速度控制程式撰寫與測試，並尋找控制步進馬達程式庫，使其能達成角度控制。

Summary of Outcomes

-Task 1:

伺服馬達的速度控制，我參考了伺服馬達，回授控制入門 - 互動的風格 - Medium (https://medium.com/electronics-%E4%BA%92%E5%8B%95%E9%9B%BB%E5%AD%90/%E5%AF%A6%E9%AB%94%E9%81%8B%E7%AE%97week4-4943b619f476)這個網站提供的for迴圈程式，如圖1所示，不同的是，由於我需要同時我需要兩顆馬達同時作動，因而採取了while迴圈的寫法，如圖2所示，並將條件改為AND閘型式，讓控制馬達的參數都需跑到特定位置才停下。

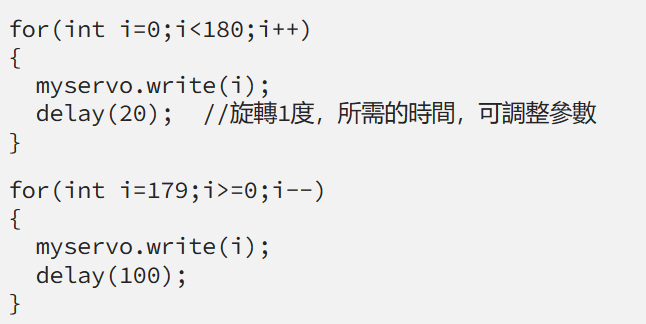
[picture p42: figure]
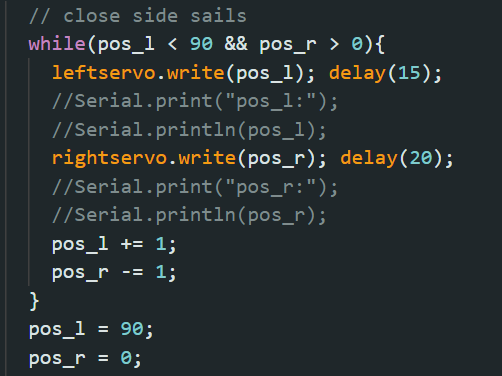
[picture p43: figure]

圖1、以for 迴圈驅動一顆馬達程式 | 圖2、以while迴圈驅動兩顆馬達程式

-Task 2:

步進馬達的程式庫，我參考了[Arduino範例] ULN2003驅動板+28BYJ-48步進馬達 (jmaker.com.tw) (https://blog.jmaker.com.tw/uln2003-28byj-48/)這個網站的教學，來做使用，其直接使用第三方函式庫Unistep2來控制步進馬達，最終，我能使用move(step)這個函數來控制馬達的角度，但也有許多可調控的參數，例如若想調整馬達的轉速，我能在建立Unistep2物件時直接調整參數，其中第五個參數為設定馬達轉一圈總共需要的步數，第六個參數則為每步的時間，因此調整這兩個參數都能讓馬達的轉速改變。

Issues and Challenge

- Challenge 1:

在調整伺服馬達速度時，我發現由於檢測開關的程式也會在同一個loop底下跑，因而在使用delay()函數讓伺服馬達在直流馬達升起主風帆後，再張開副風帆時，會不斷延遲3秒，而若再這3秒內觸碰開關後，就不會有任何反應，因而我最後須將這個delay()函數也寫再while迴圈內，使其只跑一次就停止，才能避免發生上述現象。

- Challenge 2:

在調整伺服馬達速度時，我發現若圖2的delay()中同樣輸入15ms時，不知為何rightmotor會轉得相對的快，最終，我只好將其提高到20ms讓兩顆馬達轉速大概一致，但目前仍不清楚會造成轉速不一的原因。

Perspectives

這周主要學會了如何利用arduino來控制伺服和步進馬達的角度和速度，起初原本認為角度控好就行了，經由實際經驗發現速度也是需多加考慮的一項因素，也藉由這次機會，認識了伺服馬達的內部構造與運作原理。

Plans for Next Week

- Perspective 1:

將步進馬達連接到圓盤的孔內，測試能不能轉動風帆。

- Perspective 2:

研究風帆旋轉角度策略，並試圖以程式控制。

- Perspective 3:

將新加入的電子元件畫進接線圖內。

Remarks

目前有在考慮是否有需要煞車功能，但可能要等到這周五的時間才能測試，應該會以不升起也不張開風帆得情況下測試新車子滑下去會不會還撞到草地。

Name: 林士程Week 5Page number 1

Name: 林士程Week 6Page number 7

Name: 林士程Week 6Page number 8

Name: 林士程Week 7Page number 9

Name: 林士程 Week 9Page number 11

Name: 林士程Week 8Page number 10

Name: 林士程Week 10Page number 12

Name: 林士程 Week 12Page number 14

Name: 林士程Week 11Page number 13

Name: 林士程Week 12Page number 15

Name: 林士程 Week 13Page number 17

Name: 林士程 Week 4Page number 2

Name: 林士程Week 13Page number 16

Name: 林士程Week 3Page number 2

Name: 林士程Week 4Page number 3

Name: 林士程 Week 5Page number 6

Name: 林士程Week 5Page number 4

Name: 林士程Week 5Page number 5

Name: 林士程Week 5Page number 6

ME 1011 Practice of Mechanical Engineering National Taiwan University

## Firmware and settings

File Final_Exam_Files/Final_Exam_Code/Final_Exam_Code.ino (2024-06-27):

// Library
#include <util/atomic.h> // For the ATOMIC_BLOCK macro
#include <Servo.h> // For servo motor control
#include "I2Cdev.h"// For I2C communicate
#include "MPU6050_6Axis_MotionApps612.h"//For IMU
#if I2CDEV_IMPLEMENTATION == I2CDEV_ARDUINO_WIRE
#include "Wire.h"
#endif
// Declaration
Servo leftservo;// Servo motor 
Servo rightservo;// Servo motor 
Servo turnservo;// Servo motor 
Servo liftservo;// Servo motor 
Servo right_brake_servo;  
Servo left_brake_servo; 
MPU6050 mpu;// IMU
//BOT &LED PIN
#define BUTTON 6  // interrupt only 2 3 available
#define LED 13
// measure distance parameter
#define leftphoto 2 
#define rightphoto 3
volatile long leftcounti = 0;
volatile long rightcounti = 0;
float leftphi = 0;
float rightphi = 0;
float d_leftphi = 0;
float d_rightphi = 0;
float last_leftphi = 0;
float last_rightphi = 0;
float leftdisplacement = 0;
float rightdisplacement = 0;
float wheelradius = 1.5;
float wheeldistance = 14.88;
long  leftsensorRead = 0;
long  rightsensorRead = 0;
double x = 0,y = 0,theta = 0;
unsigned long right_time = 0;
unsigned long last_right_time = 0;
unsigned long left_time = 0;
unsigned long last_left_time = 0;
unsigned long time = 0;
#define OUTPUT_READABLE_YAWPITCHROLL
// #define INTERRUPT_PIN 2  // use pin 2 on Arduino Uno & most boards
//time interval
#define interval_1 500
#define interval_2 1500
#define interval_3 3800
#define interval_4 2000
#define interval_5 5000 
// Botton Parameter
int led_state = LOW;      
int button_state;          
int last_button_state = HIGH;  
unsigned long last_debounce_time = 0; 
unsigned long debounce_delay = 50;   
// Motor State
int state = 0;
int i = 0;
int pos_left = 145;
int pos_right = 35;
int pos_lift = 10;
int pos_turn = 90;
// MPU control/status vars
bool dmpReady = false;  // set true if DMP init was successful
uint8_t mpuIntStatus;   // holds actual interrupt status byte from MPU
uint8_t devStatus;      // return status after each device operation (0 = success, !0 = error)
uint16_t packetSize;    // expected DMP packet size (default is 42 bytes)
uint16_t fifoCount;     // count of all bytes currently in FIFO
uint8_t fifoBuffer[64]; // FIFO storage buffer
// orientation/motion vars
Quaternion q;           // [w, x, y, z]         quaternion container
VectorInt16 aa;         // [x, y, z]            accel sensor measurements
VectorInt16 gy;         // [x, y, z]            gyro sensor measurements
VectorInt16 aaReal;     // [x, y, z]            gravity-free accel sensor measurements
VectorInt16 aaWorld;    // [x, y, z]            world-frame accel sensor measurements
VectorFloat gravity;    // [x, y, z]            gravity vector
float ypr[3];           // [yaw, pitch, roll]   yaw/pitch/roll container and gravity vector
double yaw;
// time_interval vars
unsigned long current_time = 0;
unsigned long start_time = 0;
// ================================================================
// ===               INTERRUPT DETECTION ROUTINE                ===
// ================================================================
volatile bool mpuInterrupt = false;     // indicates whether MPU interrupt pin has gone high
void dmpDataReady() {
  mpuInterrupt = true;
}
////////////////////        SETUP        ////////////////////

void setup() {
  pinMode(BUTTON, INPUT_PULLUP);; //set as pull-up resistor
  pinMode(LED,OUTPUT);
  IMU_Initialize();
  right_brake_servo.attach(4);
  left_brake_servo.attach(5);
  liftservo.attach(8);
  leftservo.attach(9);
  rightservo.attach(10);
  turnservo.attach(11);
  right_brake_servo.write(90);
  left_brake_servo.write(90);
  pinMode(leftphoto, INPUT);
  pinMode(rightphoto, INPUT);
  attachInterrupt(digitalPinToInterrupt(rightphoto),rightcount,RISING);
  attachInterrupt(digitalPinToInterrupt(leftphoto),leftcount,RISING);
}
////////////////////        LOOP        ////////////////////
void loop() {
  Serial.print("state:");
  Serial.println(state);
  if (state==0){
    liftservo.write(10);
    leftservo.write(145);
    rightservo.write(35);
    turnservo.write(90);
    ReadAndDebounceBotton();
  }
  if (state==1){
    led_state = !led_state;// LED dark->light
    digitalWrite(LED,led_state); //LED light
    for(start_time = millis() ;  current_time < start_time + interval_1 ; current_time = millis()){
    }    
    state++;
  }
  if(state == 2){ 
    brake();
    open_sails();
    cancel_brake();
    state++;
  }
  if (state == 3){
    turn_sail(160);
    for(start_time = millis() ;  current_time < start_time + interval_2 ; current_time = millis()){
      brake();
    }
    cancel_brake();
    for(start_time = millis() ;  current_time < start_time + interval_3 ; current_time = millis()){
      turn_sail_with_IMU(160);
    }
    for(start_time = millis() ;  current_time < start_time + interval_4 ; current_time = millis()){
      brake();
    }
    cancel_brake();
    for(start_time = millis() ;  current_time < start_time + interval_5 ; current_time = millis()){
      turn_sail_with_IMU(15);
    }  
    state++;
  }
  if (state == 4){
    ReadAndDebounceBotton();
    Serial.println(pos_turn);
  }
  if (state == 5){
    led_state = !led_state;// light->dark
    digitalWrite(LED,led_state); //dark
    close_turn_sail();
    close_main_sail();
    close_side_sails();
    state = 0; 
  }
}
////////////////////        FUNCTION        ////////////////////
void ReadAndDebounceBotton(){
  int reading = digitalRead(BUTTON);
  if (reading != last_button_state) {
    last_debounce_time = millis();
  }
  if ((millis() - last_debounce_time) > debounce_delay) {
    if (reading != button_state) {
      button_state = reading;
      if (button_state == LOW) {
        state++;
      }
    }
  }
  last_button_state = reading;
}
void open_sails(){
  while((pos_lift < 175) && ( pos_left > 45 && pos_right < 135 )){
      liftservo.write(pos_lift); 
      leftservo.write(pos_left); 
      rightservo.write(pos_right);
      delay(20);
      if(pos_lift < 175){
        pos_lift += 2;
      }
      Serial.print((pos_lift < 175) && ( pos_left > 45 && pos_right < 135 ));
      Serial.print("\t");
      Serial.println(pos_lift);
      if(pos_left > 45 && pos_right < 135){
        pos_left -= 1;
        pos_right += 1;
      }
    }
}
void IMU_Initialize(){
    // join I2C bus (I2Cdev library doesn't do this automatically)
  #if I2CDEV_IMPLEMENTATION == I2CDEV_ARDUINO_WIRE
    Wire.begin();
    Wire.setClock(400000); // 400kHz I2C clock. Comment this line if having compilation difficulties
    Wire.setWireTimeout(3000, true);
  #elif I2CDEV_IMPLEMENTATION == I2CDEV_BUILTIN_FASTWIRE
    Fastwire::setup(400, true);
  #endif
  // initialize serial communication
  Serial.begin(115200);
  while (!Serial); // wait for Leonardo enumeration, others continue immediately
  // initialize device
  Serial.println(F("Initializing I2C devices..."));
  mpu.initialize();
  //pinMode(INTERRUPT_PIN, INPUT);
  // verify connection
  Serial.println(F("Testing device connections..."));
  Serial.println(mpu.testConnection() ? F("MPU6050 connection successful") : F("MPU6050 connection failed"));
  // wait for ready
  // Serial.println(F("\nSend any character to begin DMP programming and demo: "));
  while (Serial.available() && Serial.read()); // empty buffer
  // while (!Serial.available());                 // wait for data
  // while (Serial.available() && Serial.read()); // empty buffer again

  // load and configure the DMP
  Serial.println(F("Initializing DMP..."));
  devStatus = mpu.dmpInitialize();
  // make sure it worked (returns 0 if so)
  if (devStatus == 0) {
    // Calibration Time: generate offsets and calibrate our MPU6050
    mpu.CalibrateAccel(15);
    mpu.CalibrateGyro(15);
    Serial.println();
    mpu.PrintActiveOffsets();
    // turn on the DMP, now that it's ready
    Serial.println(F("Enabling DMP..."));
    mpu.setDMPEnabled(true);

    // enable Arduino interrupt detection
    Serial.print(F("Enabling interrupt detection (Arduino external interrupt "));
    //Serial.print(digitalPinToInterrupt(INTERRUPT_PIN));
    Serial.println(F(")..."));
    //attachInterrupt(digitalPinToInterrupt(INTERRUPT_PIN), dmpDataReady, RISING);
    Serial.println(mpuInterrupt);
    mpuIntStatus = mpu.getIntStatus();
    // set our DMP Ready flag so the main loop() function knows it's okay to use it
    Serial.println(F("DMP ready! Waiting for first interrupt..."));
    dmpReady = true;
    // get expected DMP packet size for later comparison
    packetSize = mpu.dmpGetFIFOPacketSize();
  } else {
    // ERROR!
    // 1 = initial memory load failed
    // 2 = DMP configuration updates failed
    // (if it's going to break, usually the code will be 1)
    Serial.print(F("DMP Initialization failed (code "));
    Serial.print(devStatus);
    Serial.println(F(")"));
  }
  //Check FullScaleRange 
    Serial.print("GyroRange:");
    Serial.print(mpu.getFullScaleGyroRange());
    // 0 = +/- 250 degrees/sec
    // 1 = +/- 500 degrees/sec
    // 2 = +/- 1000 degrees/sec
    // 3 = +/- 2000 degrees/sec *
    Serial.print("\tAccelRange:");
    Serial.print(mpu.getFullScaleAccelRange());
    // 0 = +/- 2g *
    // 1 = +/- 4g
    // 2 = +/- 8g
    // 3 = +/- 16g
}
void IMU_Read(){
// if programming failed, don't try to do anything
  if (!dmpReady) return;
  // read a packet from FIFO
  if (mpu.dmpGetCurrentFIFOPacket(fifoBuffer)) { // Get the Latest packet 
    #ifdef OUTPUT_READABLE_YAWPITCHROLL
    // display Euler angles in degrees
    mpu.dmpGetQuaternion(&q, fifoBuffer);
    mpu.dmpGetGravity(&gravity, &q);
    mpu.dmpGetYawPitchRoll(ypr, &q, &gravity);
    Serial.print("ypr\t");
    Serial.print(ypr[0] * 180 / M_PI);
    Serial.print("\t");
    Serial.print(ypr[1] * 180 / M_PI);
    Serial.print("\t");
    Serial.print(ypr[2] * 180 / M_PI);
    /*
      mpu.dmpGetAccel(&aa, fifoBuffer);
      Serial.print("\tRaw Accl XYZ\t");
      Serial.print(aa.x);
      Serial.print("\t");
      Serial.print(aa.y);
      Serial.print("\t");
      Serial.print(aa.z);
      mpu.dmpGetGyro(&gy, fifoBuffer);
      Serial.print("\tRaw Gyro XYZ\t");
      Serial.print(gy.x);
      Serial.print("\t");
      Serial.print(gy.y);
      Serial.print("\t");
      Serial.print(gy.z);
    */
    Serial.println();
    yaw = ypr[0] *180 / M_PI;
    #endif
  }
}
void rightcount(){
  right_time = millis();
  if (right_time - last_right_time >= 50) {
    rightcounti++;
  }
  last_right_time = right_time;
}
void leftcount(){
  left_time = millis();
  if (left_time - last_left_time >= 50) {
    leftcounti++;
  }
  last_left_time = left_time;
}
float Distance(){
  // wheel distance
  leftsensorRead = digitalRead(leftphoto); 
  rightsensorRead = digitalRead(rightphoto);
  Serial.print("rightsensorRead:");
  Serial.print(rightsensorRead);
  Serial.print("\tleftsensorRead:");
  Serial.print(leftsensorRead);
  long left_count = 0;
  long right_count = 0;
  ATOMIC_BLOCK(ATOMIC_RESTORESTATE) {
    right_count = rightcounti;
    left_count = leftcounti;
  }
  Serial.print("\trightcount:");
  Serial.print(rightcounti);
  Serial.print("\tleftcount:");
  Serial.print(leftcounti);
  if (millis() - time >= 1){ 
    rightphi = right_count * 2.0 * PI / 24.0;
    leftphi = left_count * 2.0 * PI / 24.0;
    d_rightphi = rightphi - last_rightphi;
    d_leftphi =  leftphi - last_leftphi;
    theta += (wheelradius*d_rightphi/ (wheeldistance) ) - (wheelradius * d_leftphi/ (wheeldistance) );
    x += cos(theta) * (wheelradius*d_rightphi/2.0 + wheelradius*d_leftphi/2.0);
    y += sin(theta) * (wheelradius*d_rightphi/2.0 + wheelradius*d_leftphi/2.0);
    time = millis();

    last_rightphi = rightphi;
    last_leftphi =  leftphi;
  }

  Serial.print("\t x:");
  Serial.print(x);
  Serial.print("\t y:");
  Serial.print(y);
  Serial.print("\t theta:");
  Serial.println(theta);
  return(x);
}
void brake(){
  right_brake_servo.write(80);
  left_brake_servo.write(99);
}
void cancel_brake(){
  right_brake_servo.write(90);
  left_brake_servo.write(90);
}
void turn_sail(int turn_angle){
  while(pos_turn < turn_angle){
    turnservo.write(pos_turn); delay(10);
    pos_turn += 1;
  }
}
void turn_sail_with_IMU(int turn_angle){
  IMU_Read();
  pos_turn = turn_angle + yaw;
  if(pos_turn < 0){
    pos_turn = 0;
  }
  if(pos_turn > 180){
     pos_turn =  180;
  }
  turnservo.write(pos_turn);
  Serial.println(pos_turn);
}
void close_turn_sail(){
  if(pos_turn > 90){
    while(pos_turn > 90){
    turnservo.write(pos_turn); delay(20);
    pos_turn -= 1;
    Serial.print("pos_turn:");
    Serial.println(pos_turn);
    }
  }
  else{
    while(pos_turn < 90){
    turnservo.write(pos_turn); delay(20);
    pos_turn += 1;
    Serial.print("pos_turn:");
    Serial.println(pos_turn);
    }
  }
}
void close_main_sail(){
  while(pos_lift > 10){
    liftservo.write(pos_lift); delay(20);
    pos_lift -= 1;
  }
}
void close_side_sails(){
  while(pos_left < 145 && pos_right > 35){
    leftservo.write(pos_left); delay(5);
    rightservo.write(pos_right); delay(5);
    pos_left += 1;
    pos_right -= 1;
  }   
}

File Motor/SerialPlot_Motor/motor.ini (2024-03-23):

[MainWindow]
size=@Size(1327 1321)
pos=@Point(1230 0)
activePanel=Plot
hidePanels=false
maximized=false
state=@ByteArray(\0\0\0\xff\0\0\0\0\xfd\0\0\0\0\0\0\x5/\0\0\x4\xc2\0\0\0\x4\0\0\0\x4\0\0\0\b\0\0\0\b\xfc\0\0\0\x1\0\0\0\x2\0\0\0\x3\0\0\0\f\0t\0\x62\0P\0l\0o\0t\x1\0\0\0\0\xff\xff\xff\xff\0\0\0\0\0\0\0\0\0\0\0\x1a\0t\0\x62\0P\0o\0r\0t\0\x43\0o\0n\0t\0r\0o\0l\x1\0\0\0\x91\xff\xff\xff\xff\0\0\0\0\0\0\0\0\0\0\0\x10\0t\0\x62\0R\0\x65\0\x63\0o\0r\0\x64\x1\0\0\x2\"\xff\xff\xff\xff\0\0\0\0\0\0\0\0)

[Port]
selectedPort=COM3
baudRate=9600
parity=none
dataBits=8
stopBits=1
flowControl=none

[DataFormat]
format=ascii

[DataFormat_Binary]
numOfChannels=1
numberFormat=uint8
endianness=little

[DataFormat_ASCII]
numOfChannels=auto
delimiter=","
customDelimiter=|
filterMode=disabled
filterPrefix=

[DataFormat_CustomFrame]
numOfChannels=1
numberFormat=uint8
endianness=little
frameStart=AA BB
fixedSize=false
frameSize=1
checksum=false
debugMode=false

[Channels]
channel\1\name=target position
channel\1\color=@Variant(\0\0\0\x43\x1\xff\xff\xff\xff\b\b\x14\x14\0\0)
channel\1\visible=true
channel\1\gain=1
channel\1\gainEnabled=false
channel\1\offset=0
channel\1\offsetEnabled=false
channel\2\name=current postion
channel\2\color=@Variant(\0\0\0\x43\x1\xff\xffUU\xff\xff\x7f\x7f\0\0)
channel\2\visible=true
channel\2\gain=1
channel\2\gainEnabled=false
channel\2\offset=0
channel\2\offsetEnabled=false
channel\3\name=target angle
channel\3\color=@Variant(\0\0\0\x43\x1\xff\xffUUUU\xff\xff\0\0)
channel\3\visible=true
channel\3\gain=1
channel\3\gainEnabled=false
channel\3\offset=0
channel\3\offsetEnabled=false
channel\4\name=current angle
channel\4\color=@Variant(\0\0\0\x43\x1\xff\xff\xf3\xf3\xfe\xfe{{\0\0)
channel\4\visible=true
channel\4\gain=1
channel\4\gainEnabled=false
channel\4\offset=0
channel\4\offsetEnabled=false
channel\size=4

[Plot]
numOfSamples=1000
plotWidth=1000
indexAsX=true
xMax=10
xMin=0
autoScale=false
yMax=127
yMin=-128
darkBackground=true
grid=true
minorGrid=false
legend=true
multiPlot=false
symbols=auto
numLines=1000
decimals=6

[Commands]
command\1\name=Command 1
command\1\type=ascii
command\1\data=
command\size=1

[Record]
autoIncrement=true
recordPaused=true
stopOnClose=true
header=true
disableBuffering=false
separator=","
decimals=6
timestamp=true
timestampFormat=seconds

[UpdateCheck]
periodicCheck=true
lastCheck=2024-03-23

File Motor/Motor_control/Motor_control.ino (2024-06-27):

// Library
#include <util/atomic.h> // For the ATOMIC_BLOCK macro
#include <Servo.h> // For servo motor control
// IO PIN
#define BUTTON 3  // interrupt only 2 3 available
#define ENCA 2 // Green interrupt only 2 3 available
#define ENCB 5 // Yellow
#define PWM 11
#define IN2 6
#define IN1 7
#define LED 13
// PID Parameters
volatile int posi = 0;
long prevT = 0;
float eprev = 0;
float eintegral = 0;
// Encoder Parameters
float gear_ratio = 45.0; 
float encoder_resolution = 11.0;
float current_angle = 0.0;
// Botton Parameter
int led_state = LOW;      
int button_state;          
int last_button_state = HIGH;  
unsigned long last_debounce_time = 0; 
unsigned long debounce_delay = 50;   
// Motor State
int state = 0;
int i = 0;
int tes = 0;
int pos_l = 90;
int pos_r = 0;
// Servo motor declare
Servo leftservo;
Servo rightservo;
int starttime;int duration;int ontime = 300;
////////////////////        SETUP        ////////////////////

void setup() {
  Serial.begin(9600);
  pinMode(BUTTON, INPUT_PULLUP);; //set as pull-up resistor
  pinMode(ENCA,INPUT);
  pinMode(ENCB,INPUT);
  pinMode(PWM,OUTPUT);
  pinMode(IN1,OUTPUT);
  pinMode(IN2,OUTPUT);
  pinMode(LED,OUTPUT);
  attachInterrupt(digitalPinToInterrupt(ENCA),readEncoder,RISING);
  leftservo.attach(9);
  rightservo.attach(10);
}
////////////////////        LOOP        ////////////////////
void loop() {
  //Serial.println(state);
  if (state==0){
    leftservo.write(90);
    rightservo.write(0);
    ReadAndDebounceBotton();
  }
  if (state==1){
    led_state = !led_state;// dark->light
    digitalWrite(LED,led_state); //light
    delay(2000);
    state++;
  }
  if(state == 2){ 
    // raise the main sail 
    //PIDControlMotor(-70,1.7,0.0,0.0);
    PIDControlMotor(-130,1.1,0.0,0.1);
    //wait until main sail raise
    //setMotor(1,140,PWM,IN1,IN2);
    // open side sail
    while(pos_l> 0 && pos_r < 90){
      leftservo.write(pos_l); delay(5);
      //Serial.print("pos_l:");
      //Serial.println(pos_l);
      rightservo.write(pos_r); delay(5);
      //Serial.print("pos_r:");
      //Serial.println(pos_r);
      pos_l -= 1;
      pos_r += 1;
    }
    ReadAndDebounceBotton();   
  }
  if (state==3){
    setMotor(0,0,PWM,IN1,IN2);
    led_state = !led_state;// light->dark
    digitalWrite(LED,led_state); //dark
    state = 0; 
    //close side sails 
    while(pos_l < 90 && pos_r > 0){
      leftservo.write(pos_l); delay(5);
      //Serial.print("pos_l:");
      //Serial.println(pos_l);
      rightservo.write(pos_r); delay(5);
      //Serial.print("pos_r:");
      //Serial.println(pos_r);
      pos_l += 1;
      pos_r -= 1;
    }  
  }
}
////////////////////        FUNCTION        ////////////////////
void setMotor(int dir, int pwmVal, int pwm, int in1, int in2){
  analogWrite(pwm,pwmVal);
  if(dir == 1){
    digitalWrite(in1,HIGH);
    digitalWrite(in2,LOW);
  }
  else if(dir == -1){
    digitalWrite(in1,LOW);
    digitalWrite(in2,HIGH);
  }
  else{
    digitalWrite(in1,LOW);
    digitalWrite(in2,LOW);
  }  
}
void readEncoder(){
  int b = digitalRead(ENCB);
  if(b > 0){
    posi++;
  }
  else{
    posi--;
  }
}
void ReadAndDebounceBotton(){
  int reading = digitalRead(BUTTON);
  if (reading != last_button_state) {
    last_debounce_time = millis();
  }
  if ((millis() - last_debounce_time) > debounce_delay) {
    if (reading != button_state) {
      button_state = reading;
      if (button_state == LOW) {
        state++;
      }
    }
  }
  last_button_state = reading;
}
void PIDControlMotor(float target_angle,float kp,float ki,float kd){
  int target = gear_ratio * encoder_resolution * target_angle / 360.0;
  // Time difference
  long currT = micros();
  float deltaT = ((float) (currT - prevT))/( 1.0e6 );
  prevT = currT;
  // Read the position in an atomic block to avoid a potential
  // misread if the interrupt coincides with this code running
  // see: https://www.arduino.cc/reference/en/language/variables/variable-scope-qualifiers/volatile/
  int pos = 0; 
  ATOMIC_BLOCK(ATOMIC_RESTORESTATE) {
    pos = posi;
  }
  // error
  int e = pos - target;
  // derivative
  float dedt = (e-eprev)/(deltaT);
  // integral
  eintegral = eintegral + e*deltaT;
  // control signal
  float u = kp*e + kd*dedt + ki*eintegral;
  // motor power
  float pwr = fabs(u);
  if( pwr > 255 ){ //   256*(12/14.8) = 194.4 
    pwr = 255;
  }
  // motor direction
  int dir = 1;
  if(u<0){
    dir = -1;
  }
  // signal the motor
  setMotor(dir,pwr,PWM,IN1,IN2);
  // store previous error
  eprev = e;
  current_angle = pos * 360.0 / gear_ratio / encoder_resolution;
  Serial.print(target);
  Serial.print(",");
  Serial.print(pos);
  Serial.print(",");
  Serial.print(target_angle);
  Serial.print(",");
  Serial.print(current_angle);
  Serial.print(",");
  Serial.print(dir);
  Serial.print(",");
  Serial.print(u);
  Serial.print(",");
  Serial.print(pwr);
  Serial.println(",");
}

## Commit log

2024-03-13 arduino mpu6050 signal reading
2024-03-14 rename mpu6050 code and add motor control code
2024-03-16 add mpu6050_dmp6_using_dmp
    [biplane.obj]
2024-03-16 zip files that jrowberg mpu6050 need
    [biplane.obj]
2024-03-16 add kalman filter and delete some mpu6050 files
2024-03-21 encoder codes
2024-03-22 revise motor code
2024-03-23 add encoder test
2024-03-23 encoder code writen & serialPlot file added
    [Motor PID Position control (kp = 1.45 ki =0 kd =0).csv, Motor PID Position control (kp = 1.45 ki =0 kd =0).xlsx]
2024-03-27 add motor control with switch code
    [MPU6050.csv, Motor PID Position control (kp = 1.45 ki =0 kd =0).csv, Motor PID Position control (kp = 1.45 ki =0 kd =0).xlsx]
2024-04-02 kalman update
    [Motor PID Position control (kp = 1.45 ki =0 kd =0).xlsx]
2024-04-10 servo motor
    [MPU6050.csv, biplane.obj]
2024-04-10 engineering diagram
    [18650電池盒.ipt, 9V方型電池盒.ipt, Arduino板.ipt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]
2024-04-12 personal journal
    [18650電池盒.ipt, 20240412.dwg, 9V方型電池盒.ipt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]
2024-06-27 update final
    [0805_SMD_Capacitor.ipt, 18650電池盒.0001.ipt, 18650電池盒.ipt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]
